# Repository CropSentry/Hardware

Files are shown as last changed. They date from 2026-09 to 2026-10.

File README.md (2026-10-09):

# 🌱 CropSentry

**A fully-autonomous plant disease/condition detector that runs on solar power and features LoRa capability.**

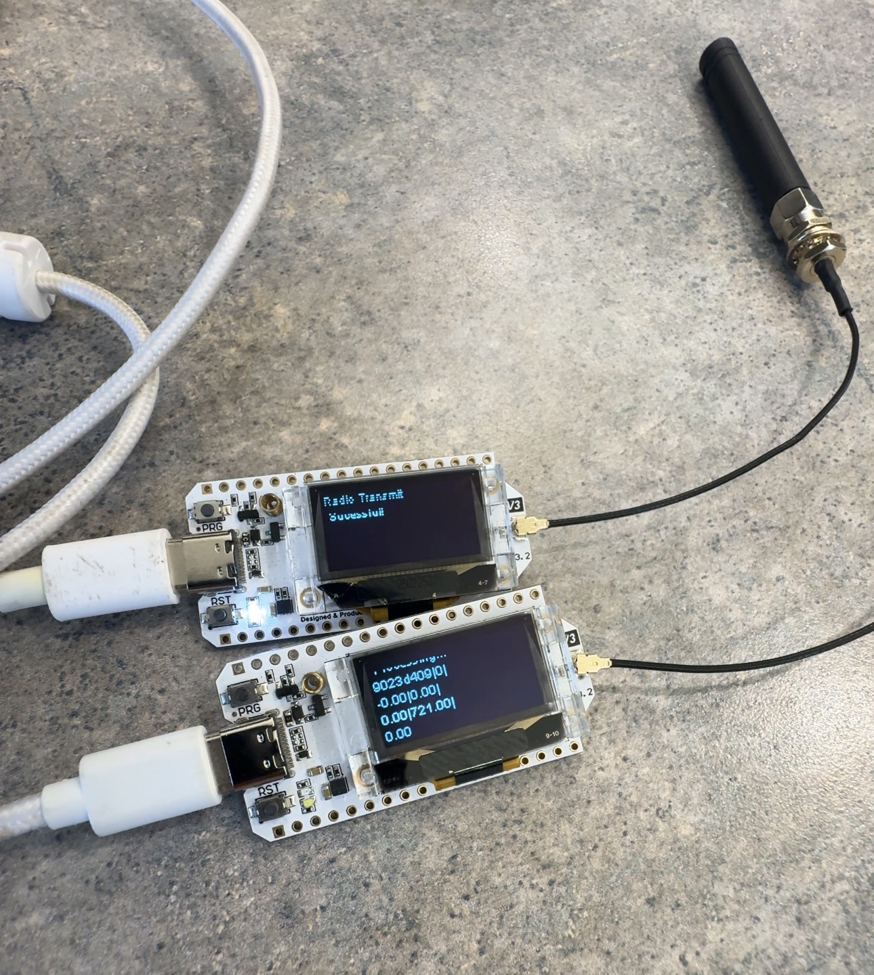
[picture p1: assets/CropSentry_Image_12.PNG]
Introduction Image 1


--------------

### 🔧 *What It Is*

**CropSentry** is an IoT device that automatically and autonomously tracks plant conditions, including VOC, temperature, soil moisture, gas, and humidity. It sits alone in a field and can monitor multiple crop sections at once. We see that through this process, an AI/ML model can use this data to determine the plant’s in-the-moment state, as well as provide an educated and accurate summary of what can show as a potential risk. 

The data path of how info will get to a user will start from the on-board module. (Cai Griffith) From there, it sends information via a LoRa connection to another board that is connected to a Wi-Fi router. The board will then send data over Wi-Fi to a high-power server (https://gear.museumofaviation.org/tech-specs/) and will compute all readings with an AI/ML system. (Jay Patel) After it’s been computed, the server will send the translated data to the CropSentry app. (Aahan Patel) From there, the user can read charts, numbers, and an AI summary of the condition of their crop.

**To summarize:**

- It's a plant disease/condition detector.
- It's a module that sends collected crop data to a powerful server for compute.
- It's a system of sensors full of cross-checking for accuracy.

--------------

### 🚗 *Drive*

CropSentry solves a real problem. Farmers all over the world need to constantly check their plants and make sure everything is doing well on a daily basis. According to statistics, over **20-40% of crops** are lost per year due to disease and environmental factors. It also says that an estimated **63+ tons of crops** and **220 billion dollars** are lost because of this.

With CropSentry, checking your crops/plants becomes automated, and you can do it all from your phone.

We see farmers as the cornerstone of our tech-evolving world, and we believe that a design like this could be very beneficial in the agricultural system.

--------------

### ⚙️ *How It Works*

The board chosen for the hardware design is the ***Heltec LoRa V3*** due to its high-level radio capabilities and adjustable range/power accessibility.

- **SGP41:** Detects VOC/NOx air pollution over a period of time using its metal-oxide sensor abilities. Sends data through Sensirion’s built-in VOC-translating algorithm. Primary gas sensor for accurate readings. Chosen for its ability to collect accurate information under low power and time.
- **BME688:** Looks specifically for temperature and humidity, but also serves as a secondary VOC sensor. Since VOCs are hard to track accurately, the BME688 can serve as an additional cross-check. Chosen for its high versatility and efficiency.
- **SHT45:**  Serves as the ambient system for temperature and humidity sensing. I also see this as another cross-check system, but it still carries weight in how data is calculated for the user. Chosen due to its low power draw, reduced pins, and sensor cross-checking abilities.
- **Capacitive Soil Moisture Probe:**  Detects soil moisture and processes all data on an ADC pin using analog information. I chose to use capacitive so the design wouldn’t corrode or get damaged during deployment.

Each sensor except the Soil Moisture Probe is connected via **I2C Connection**. The Soil Moisture Probe is connected to **GPIO 2** to receive analog signals.

--------------

### 🔋 *Power System*

```
6V 3W panel ──> Schottky ──> CN3065 charger ──> protected 18650 ──> Heltec VBAT
                                                       │
                                            load runs off the same node
```
--------------

### 💡 *Design Decisions and Potential Concerns*

- **Range:** This can be a concern, as we are not completely sure how far the LoRa system/data will transmit. This would mostly be because we are still working on designing the model (10/8/2026) and are not able to go into the testing phase yet.
- **Inaccurate Readings:** Specifically in the VOC/NOx sensors, where there is vulnerability due to them needing to be tested over time. We are virtually trusting the sensors’ datasheets to determine our readings.
- **Water Leaking**: Rainwater (especially heavy rainwater) has a possibility of breaking through the 3D-printed layer protecting the circuits. We are actively looking for a solution to this concern and are considering using remedies such as rubber seals, CNC-milled products, and absorbent material.
- **Calibration:** We are also relying on the datasheet for accurate calibration of all sensors. Similar to the BME688, we are taking multiple readings and using the median. We also have an embedded safeguard to not send data that is unrealistic and not plausible, such as, for example, a temperature reading showing as -200 Celsius.
- **Frequency:** I decided, on much advice and legal regulations, to go with the 902-928 MHz band, which is also known as the ISM band (Industrial, Scientific, and Medical band).
- **Coding Libraries:** For the hardware coding, I used the *heltec_unofficial.h*, *WiFiManager.h*, *HTTPClient.h*, *Wire.h*, *Adafruit_BME680.h*, and *Adafruit_SHT4x.h* libraries.

--------------

### 📐 *Schematic Images/PDF*

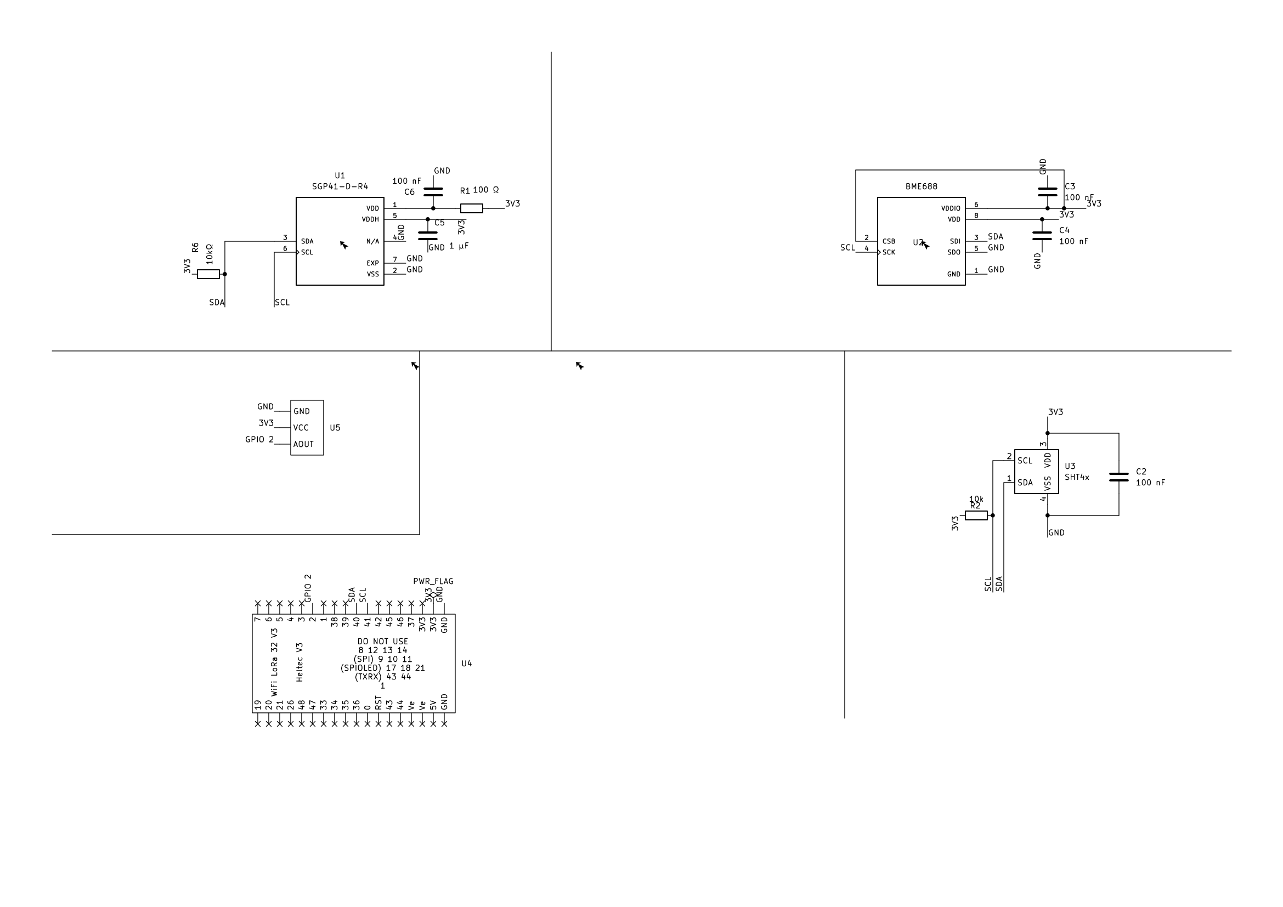
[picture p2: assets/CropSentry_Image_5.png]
Schematic PNG




--------------

### 🛠️ *CAD Images/3D Models*

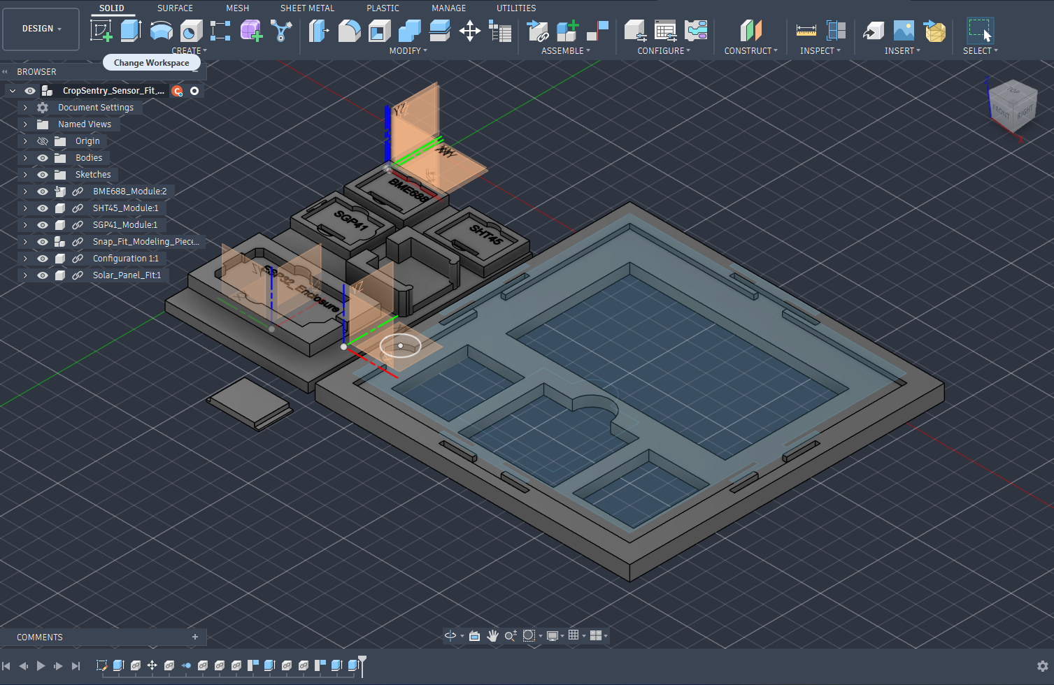
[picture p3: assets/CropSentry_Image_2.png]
CAD Image 1


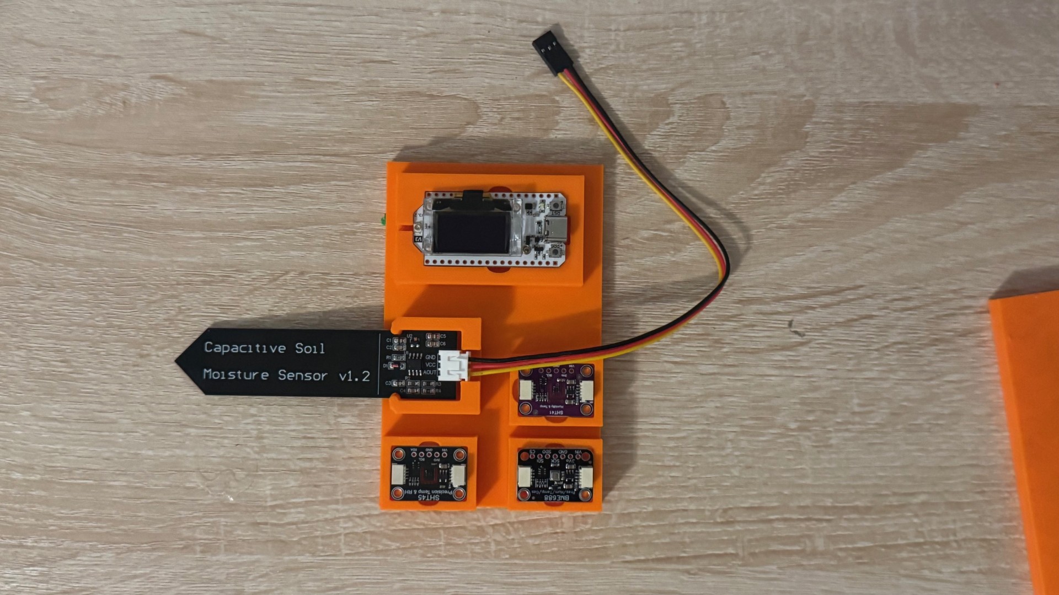
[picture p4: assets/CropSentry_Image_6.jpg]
3D Model Image 1


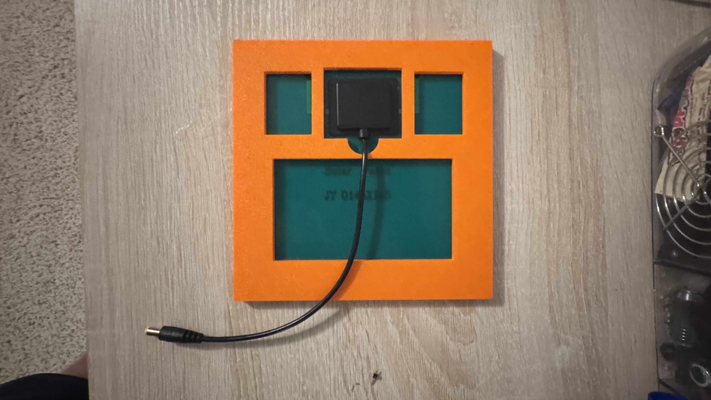
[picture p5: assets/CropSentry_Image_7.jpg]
3D Model Image 2


--------------

### 📋 *Bill of Materials*

| Part | Function | Qty | Price | Status |
| Part | Role | Qty | Cost | Status |
|---|---|---:|---:|---|
| **SGP41** | Primary VOC/NOx index sensor | 1 | $12.79 | *To buy* |
| **BME688** | Secondary gas + temp/humidity/pressure | 1 | $20.89 | ✅ Purchased |
| **SHT45** | Ambient temp/humidity reference | 1 | $14.99 | ✅ Purchased |
| **Capacitive soil probe** (EK1940, 2pk) | Soil water content, corrosion resistant | 1 | $9.99 | ✅ Purchased |
| **Heltec ESP32 LoRa V3** (w/ 1100 mAh cell + antenna) | MCU + SX1262 LoRa radio | 2 | $26.49 | ✅ 1 Purchased · 1 Donated |
| **ZPSHYD 6V 3W solar panel** | Monocrystalline, 145 × 145 mm | 1 | $14.59 | *To buy* |
| **XINLANTECH 18650 2600 mAh** | Protected Li-ion, built-in BMS | 1 | $11.72 | *To buy* |
| **CN3065 solar charge module** (3pk) | 500 mA solar Li-ion charger | 1 | $6.99 | *To buy* |
| **XT60 switch** | Battery disconnect | 1 | $8.99 | *To buy* |
| **Triple screw terminal** | Soil probe interface | 1 | — | 🔧 On hand |
| **Schottky diode** (40V 5A) | Reverse current blocking | 1 | — | 🔧 On hand |
| **Bulk electrolytic** (1000 µF 10V) | LoRa TX transient smoothing | 1 | — | 🔧 On hand |

### Budget

| Line | Submitted | Actual | Δ |
|---|---:|---:|---:|
| Subtotal | $135.43 | 127.44|-7.99 |
| Tax (7%) | $9.48 | 8.92|-0.56 |
| **Total** | **144.91**|**136.36** | **-$8.55** |
| Spent so far | $77.43 | $77.43 | — |
| **Remaining** | **67.48**|**58.93** | **-$8.55** |

*All on-hand pieces are CURRENTLY funded by me and other contributors; any money received from Stardance will go towards buying more parts needed and covering part expenses. Due to shipping and time concerns, I had to purchase parts myself to be able to continue building CropSentry on a strong timeline.*

--------------

### ⚡ *Visual Data Flow*

Architecture diagram of cropsentry/hardware (https://gitdiagram.com/cropsentry/hardware?utm_source=readme&utm_medium=picture)



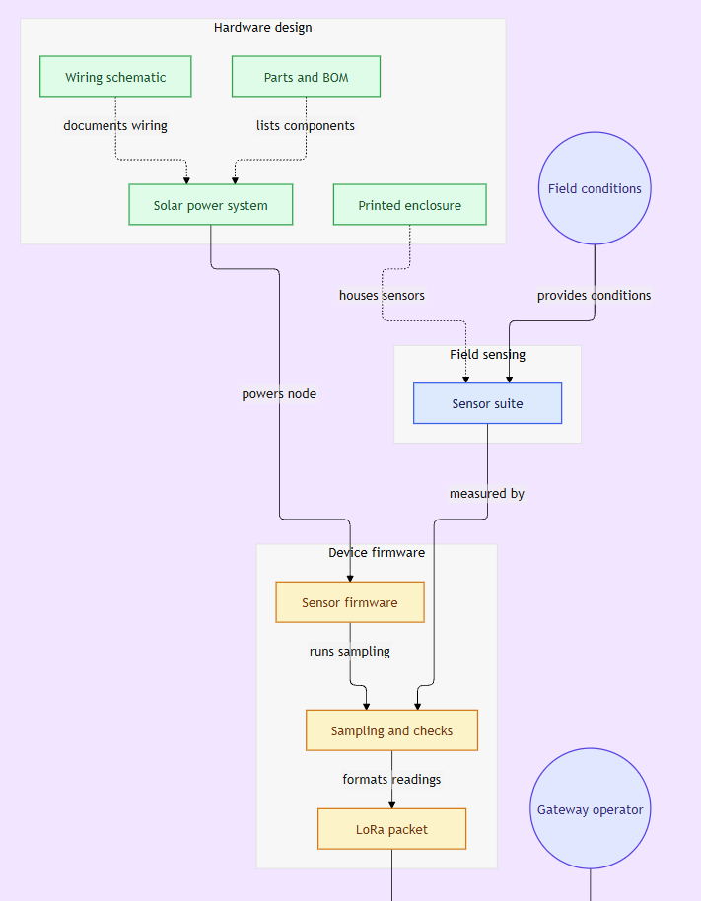
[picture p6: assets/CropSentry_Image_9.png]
Diagram Image 1

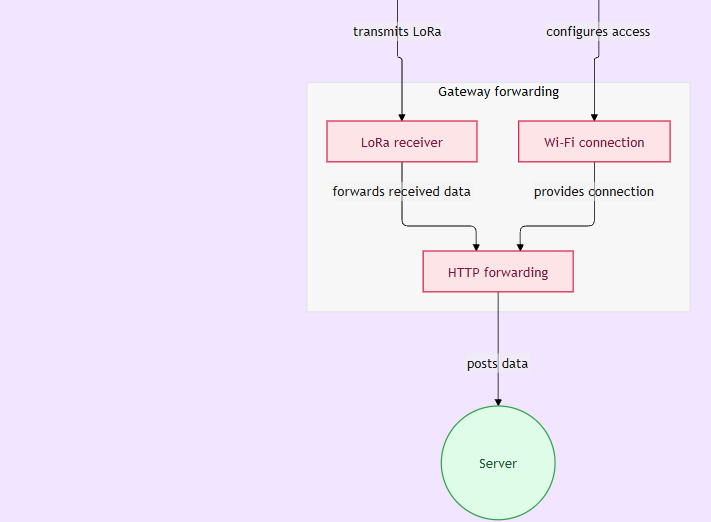
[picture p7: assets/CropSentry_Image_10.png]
Diagram Image 2


--------------

### 🔨 Building it Yourself

Make sure you have these libraries installed in your IDE/codespace: *heltec_unofficial.h v.9.2*, *WiFiManager.h v2.0.17*, *HTTPClient.h v.6.1*, *Wire.h v3.3.12*, *Adafruit_BME680.h v2.0.6*, and *Adafruit_SHT4x.h v1.0.5*.

In the receiver module code, change line 121 to your server link.

After that, make sure to plug in and run the receiver board code first; make sure to use the interactive Wi-Fi portal to connect the board to your router (You can do this by connecting to the board Wi-Fi from your device).

When the receiver board is set up, you can plug in and start the mainboard, which will automatically collect readings and send data to the receiver board.

Once that's done and all your devices are connected, everything is automated on a set timeframe, given there are no concurrent issues.

--------------

### 📄 *Extra Information*

- All CropSentry Hardware is coded in ***C++***

- The receiver code has an example link for where the server link is supposed to go due to security concerns. You must change this to send information to a server.

- CropSentry is a three-person project built for the **Congressional App Challenge** and approved as a research project through the **Middle Georgia State University CyberKnights Program**.

- ***All work regarding software, hardware, and planning is all designed by our team (only high schoolers).*** 

- We do have mentors who only give advice, but **all work is done by us**.

***Please also keep in mind that some of the files on here, such as code or 3D models, may have inaccuracies, as this is a work in progress. We are still in beta testing and are actively fixing these errors.***

--------------

### 🎬 *Presentations given at Middle Georgia State University CyberKnights Program*

**Public link to presentation created for a research meeting:** ***[Presentation View Link](https://github.com/CropSentry/Hardware/blob/main/research-presentations/Introduction/CropSentry_MGA_Presentation.pdf)***

**Public link to presentation created for an update at a research meeting (9-28-2026):** ***[Presentation View Link](https://github.com/CropSentry/Hardware/blob/main/research-presentations/Update_9-29-2026/CropSentry_Update_MGA_Presentation_9-28-2026.pdf)***

--------------

### 🏆 *Credits*

- **Hardware, power system, enclosure, and node firmware:** ***[Cai Griffith](https://www.caigriffith.dev)*** — *https://github.com/CropSentry/Hardware*
- **Application and server backend/frontend:** ***[Aahan Patel](https://github.com/HarbingerYt)*** — *https://github.com/CropSentry/MobileApp*
- **ML Design and backend:** ***[Jay Patel](https://github.com/Jay2710-09)*** — *Building ML Model; kept private in CropSentry*

--------------

### 🖼️ *Additional Images*

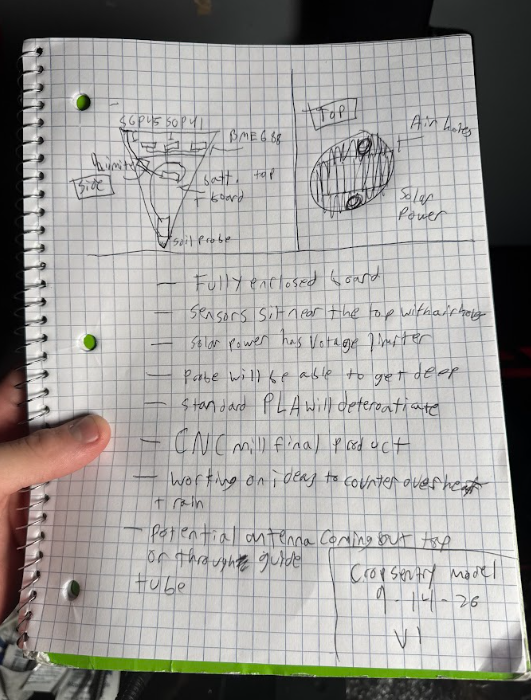
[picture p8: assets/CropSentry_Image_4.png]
Drawing Image 1

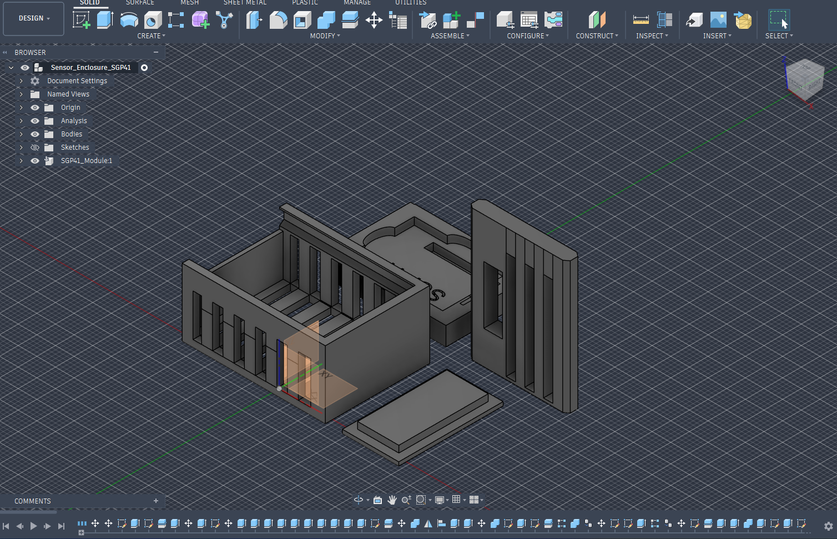
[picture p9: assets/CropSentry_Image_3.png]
CAD Image 2

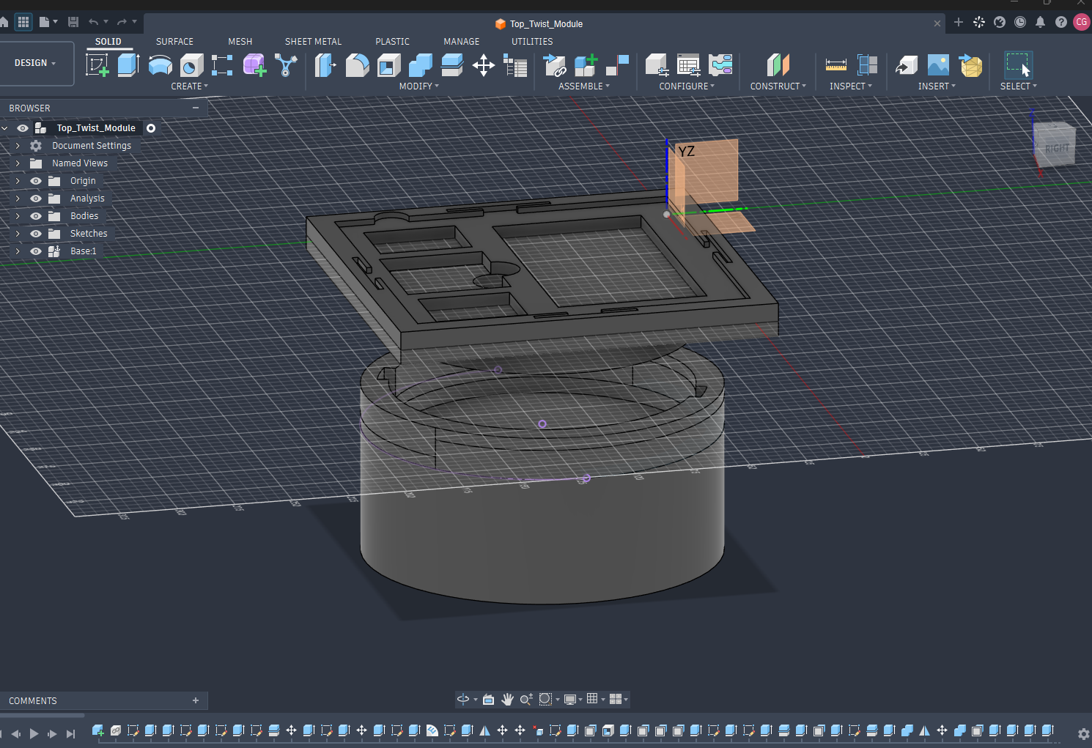
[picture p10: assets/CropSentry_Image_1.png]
CAD Image 3


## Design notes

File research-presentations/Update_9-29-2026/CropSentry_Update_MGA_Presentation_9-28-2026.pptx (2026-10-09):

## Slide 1

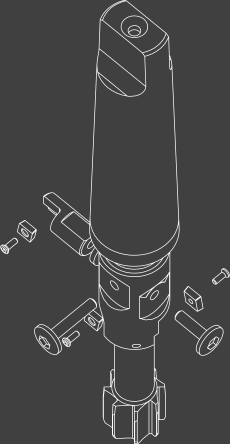
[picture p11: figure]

CropSentry
Update
Presentation

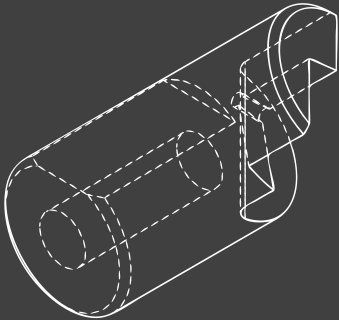
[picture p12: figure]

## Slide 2

Where we are

Currently, we are moving into the design phase of our project, pushing into physical manufacturing, finalizing code, and integrating the software/hardware.

What we’ve done

So far, we’ve made progress on all sides of CropSentry. The most notable progress is seen in App Development and Hardware with heavy advancement into further stages of building the project.

Where we plan to be

These upcoming weeks for CropSentry will be heavy on design. We plan to build physical models/prototypes, add more integration to the app and its user interface, and build a working machine learning system.

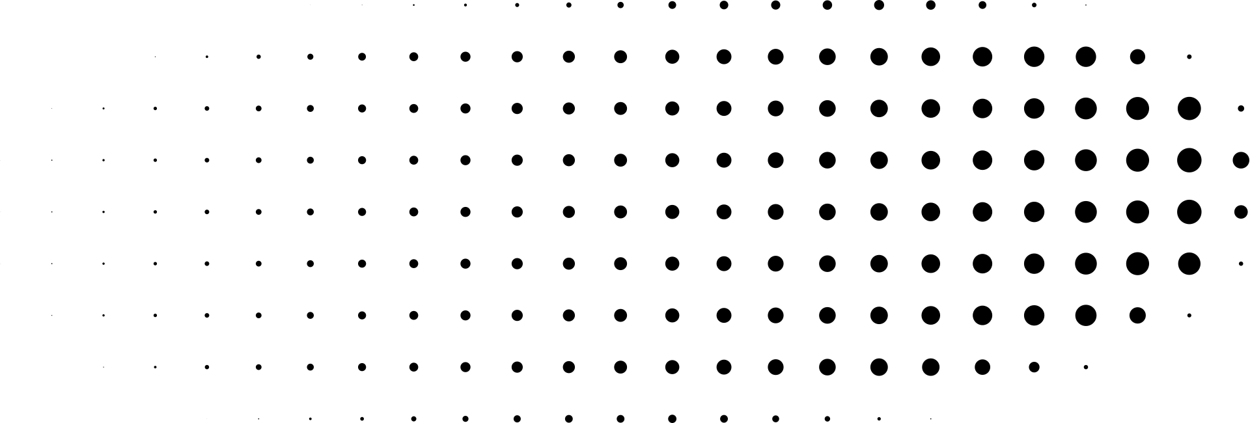
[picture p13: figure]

General Update

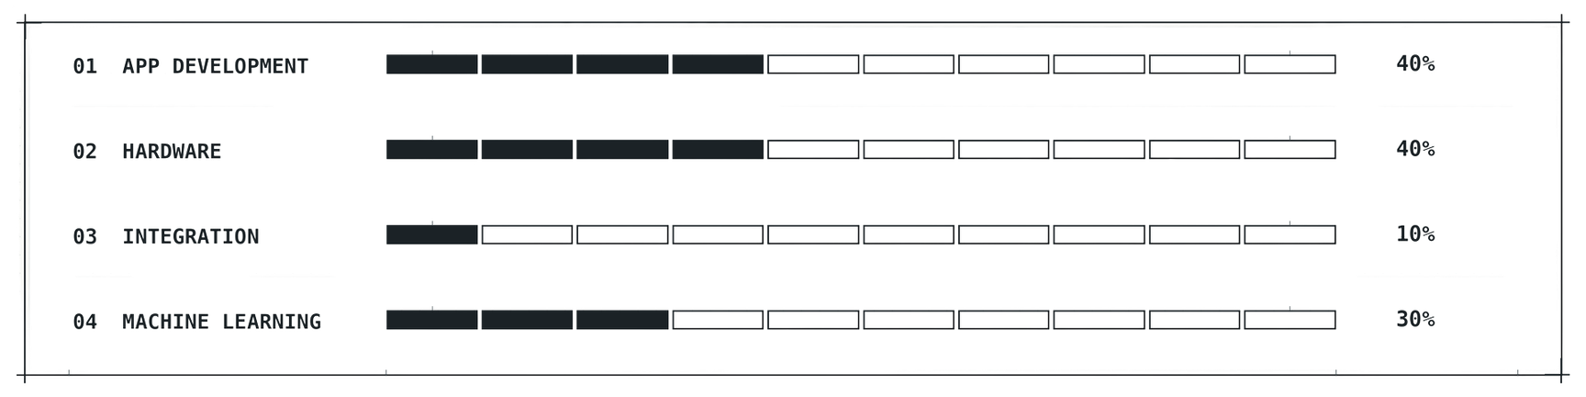
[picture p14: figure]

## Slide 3

Hardware

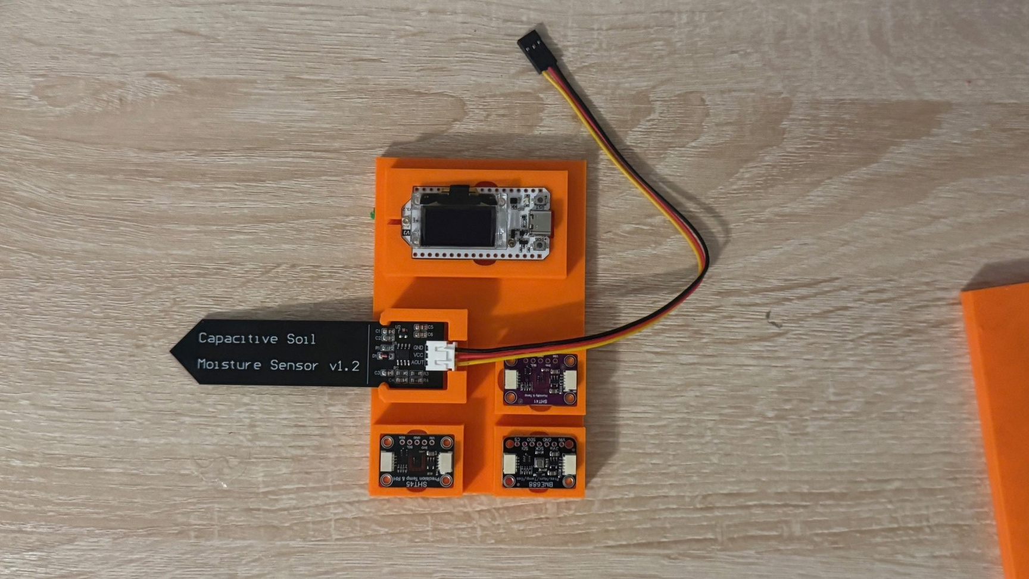
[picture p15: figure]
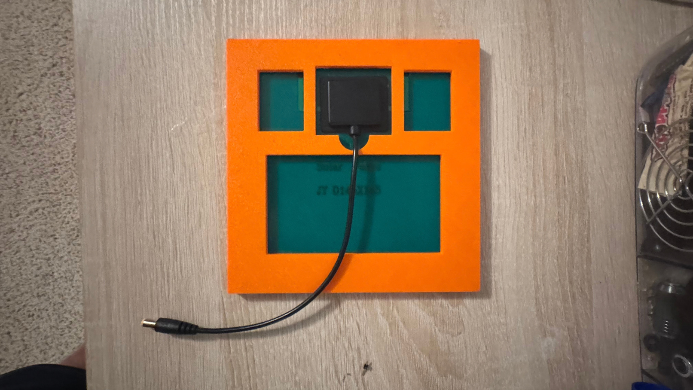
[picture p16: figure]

Prototyping

In hardware, we have physical 3D models to press-fit the sensors in, as well as a sizing estimate of how big the module will be

More Improvement

I have also built a diagram showing how the build will most likely be shaped. This will give us a valid estimate of how much area the device would take up.
In addition to that, we are close to completing the hardware code for the onboard module. The next steps for finishing it would be to write code to send the data collected over LoRa.

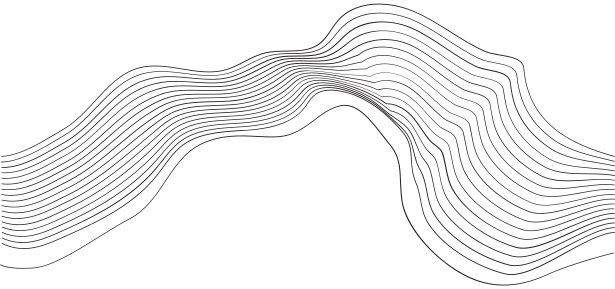
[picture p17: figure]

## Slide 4

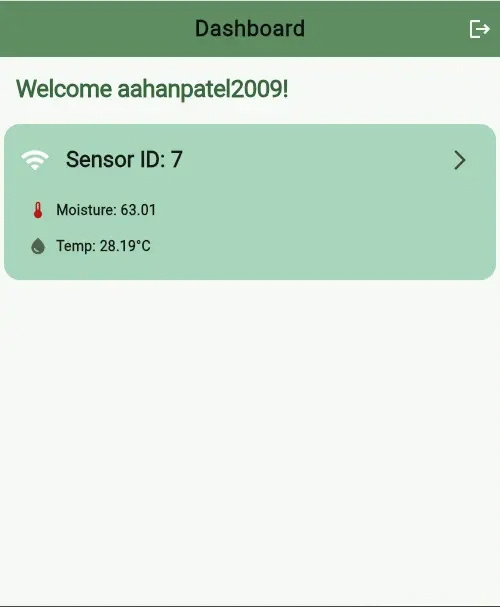
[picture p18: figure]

CropSentry App

Over the last few weeks, Aahan coded the frontend app for CropSentry. In it, you can make an account, add multiple devices, view an informational graph, and, looking further, review an AI summary of your information.

Software

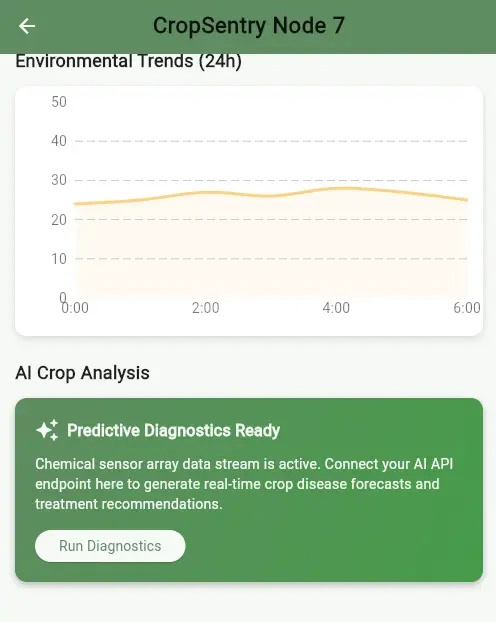
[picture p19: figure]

Looking Foward

Aahan is working on continuing the backend and is currently programming data integration throughout the app. The current goal is to get data flowing through the frontend as soon as realistically possible.
We have also recently received permission to use the Museum of Aviation’s new GEAR Lab server for app and device computation, which we will be actively working on to integrate all fields of software onto their machine.

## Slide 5

Machine Learning

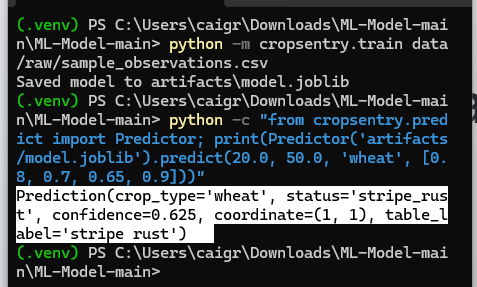
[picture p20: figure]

What is it?

The CropSentry Machine Learning System predicts whether a crop observation is healthy or has stripe_rust from temperature, moisture, crop type, and a fixed-order list of VOC measurements. Yellow-rust observations are grouped under the stripe_rust status.

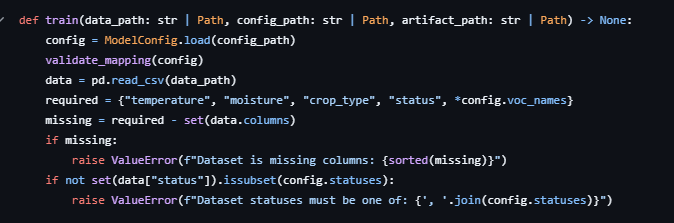
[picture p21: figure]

Progress Made

So far, Jay has coded the model to make a prediction based on a given data value. It prints 5 output variables so the user can see what a potential concern would be within their crop.

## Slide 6

See our work

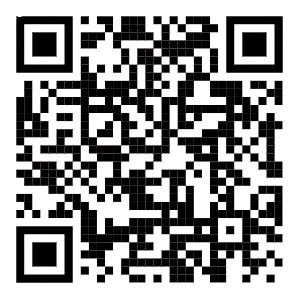
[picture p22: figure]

GitHub Link

If anyone is interested in keeping up with the CropSentry project, you can find our GitHub Organization link here:

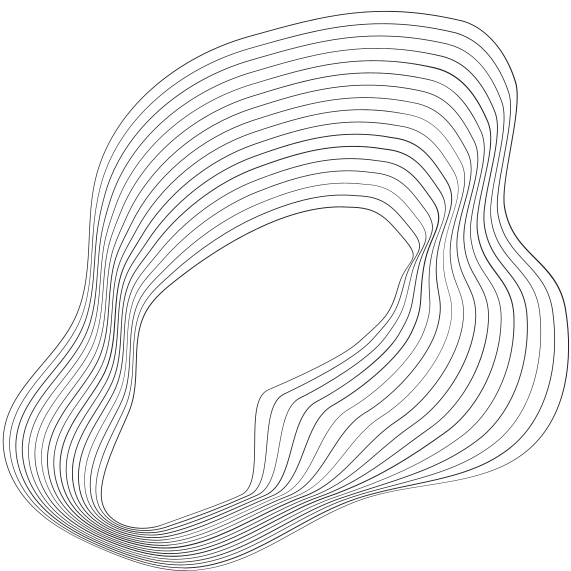
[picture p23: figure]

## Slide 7

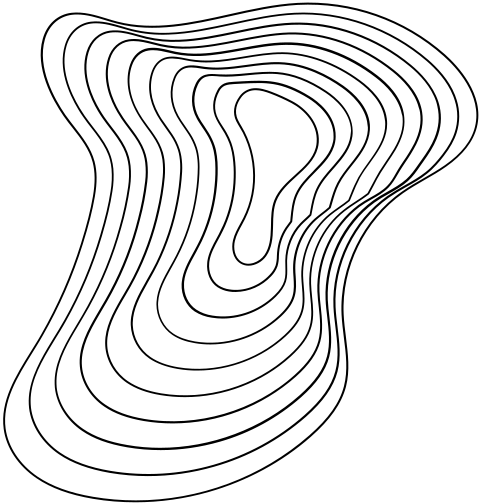
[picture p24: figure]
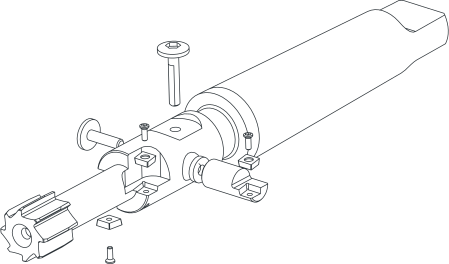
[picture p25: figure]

Q/A

Thank you for being a part of this presentation! Any questions are appreciated.

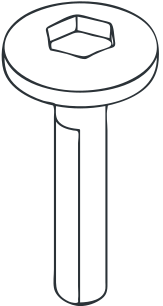
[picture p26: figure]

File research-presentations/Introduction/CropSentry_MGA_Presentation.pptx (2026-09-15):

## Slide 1


CropSentry
Research
Presentation


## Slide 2

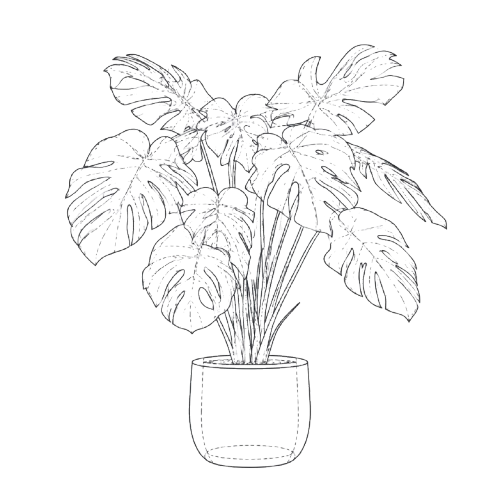
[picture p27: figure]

The Problem

Industry Concerns

Over $60B is spent annually on crop protection applied on a calendar schedule or after symptoms appear, not when stress begins.

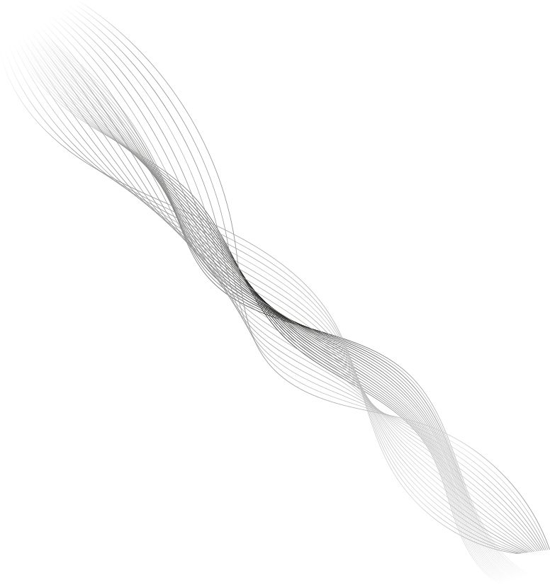
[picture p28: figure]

$220B

Lost from plant disease

20-40%

Globally lost plants due to diseases

63M+ tons

Lost crops in America from the past 4 years

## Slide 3

The Solution

Logic

VOC (Volatile Organic Compound) sensors read the air that a plant emits. A temperature and humidity sensor provides the ambient baseline, isolating the plant's signal from the environment's.
Using solar power to charge the module, CropSentry is able to run fully autonomously and without excessive maintenance.

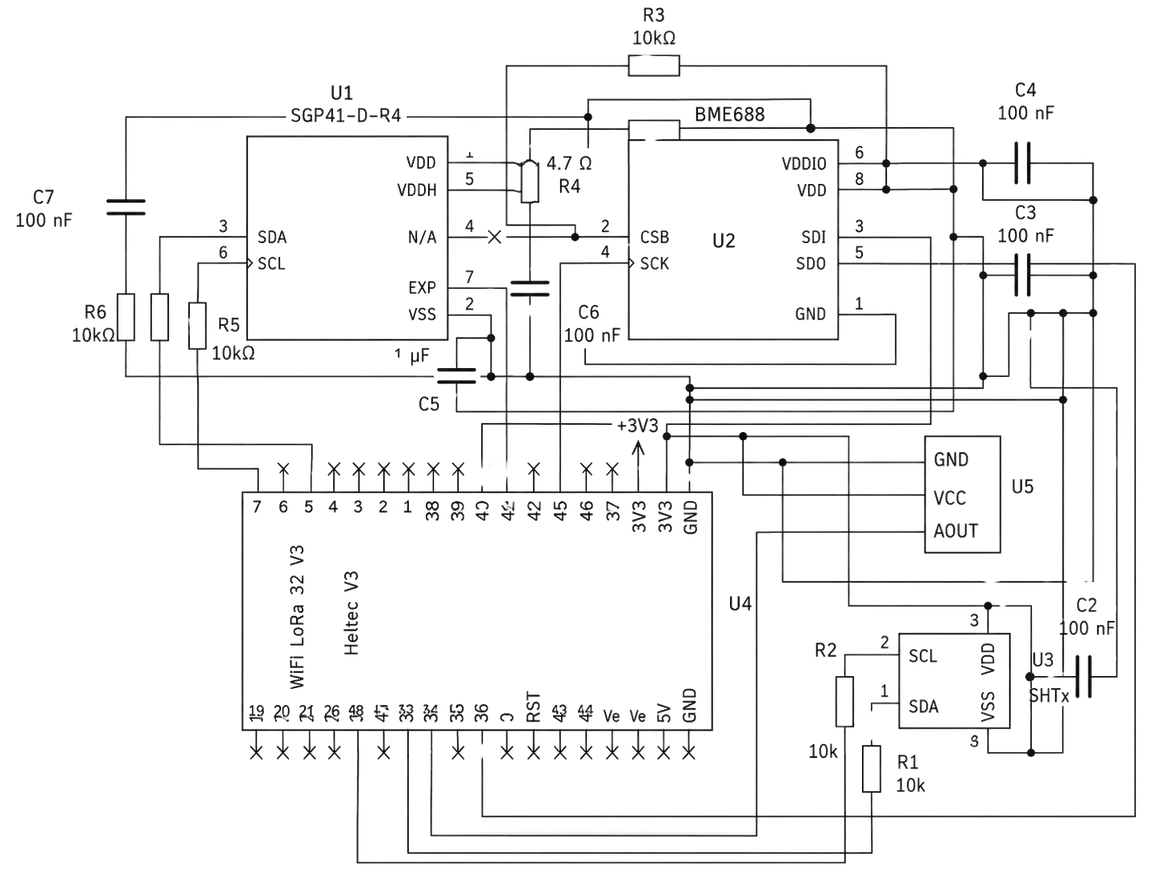
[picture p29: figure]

About the Project

CropSentry reads the compounds a plant emits, plus soil and ambient conditions, to catch stress before symptoms show. Nodes report to a gateway to your phone.


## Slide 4

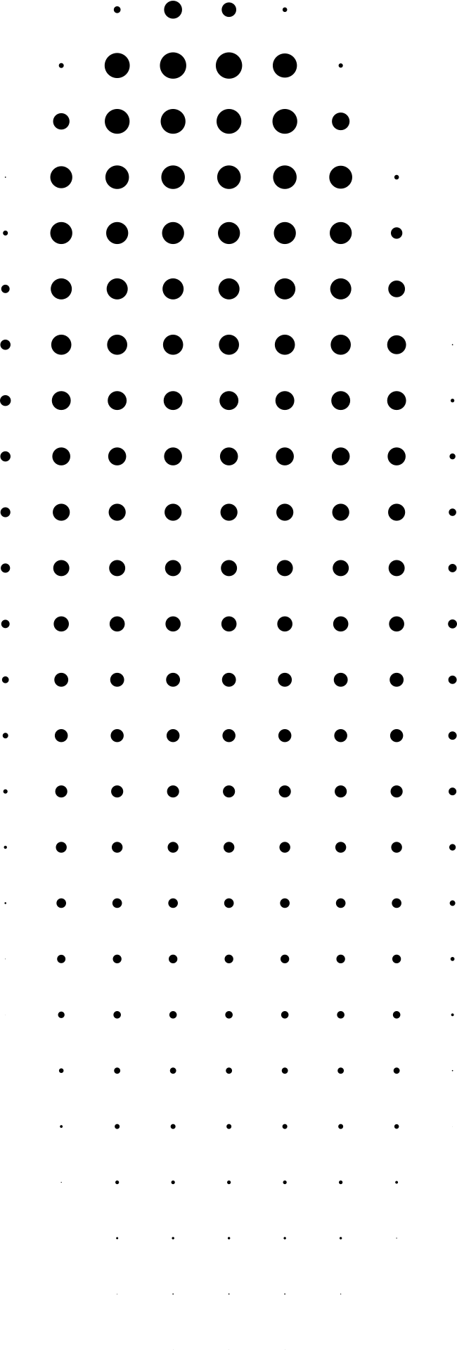
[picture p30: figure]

BME688

Checks for VOCs, temperature, humidity, and pressure

Hardware

SHT45

Secondary temperature and humidity sensor as an ambient system

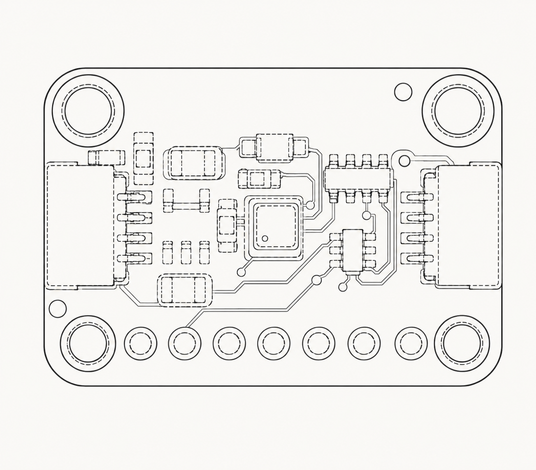
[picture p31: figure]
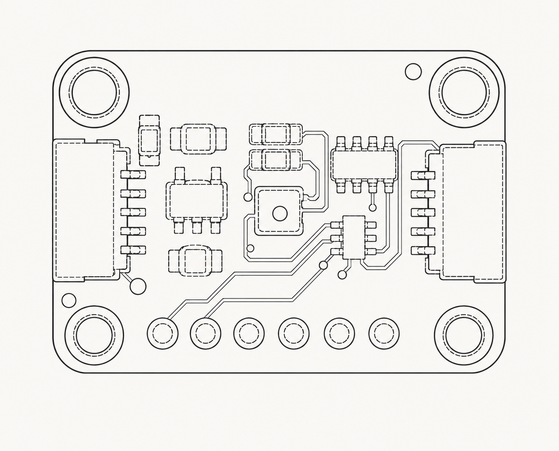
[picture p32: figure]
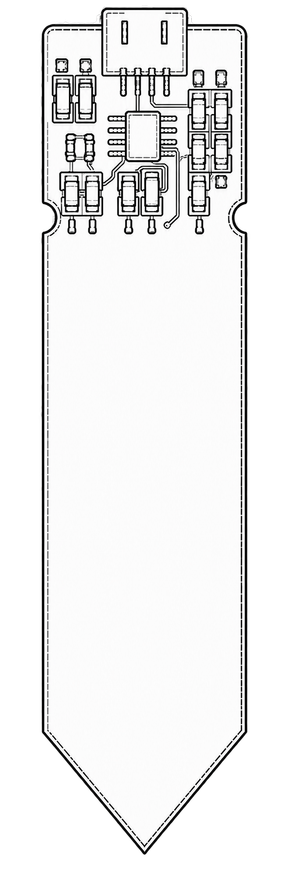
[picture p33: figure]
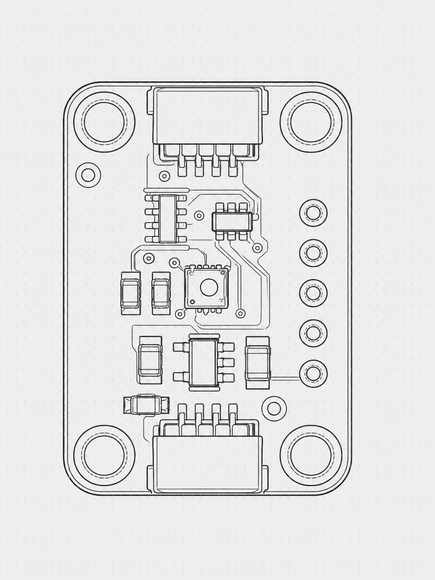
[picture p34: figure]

SGP41

Secondary VOC detection system to ensure accurate readings

Soil Moisture Probe

Detects when water in the soil is insufficient and sends an alert to the user for watering

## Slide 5


Data Logging

IO streams connecting data from server to app continuously

RT Dashboard

Live visual display of active sensor readings

History and Logs

Stored records and charts to track long-term performance

Authentication

Secure account creation, login, and profile management

ML Analysis

ML models that evaluate incoming data

Push Notifications

Instant threshold-based alerts sent to devices

Software

01


02

03


04

05


06


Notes: 1. Creating and storing user data for secure access to their farm data. This is done using Firebase Auth.
2. IO streams that connect to the server and app creating constant data streaming.
3. A machine learning model that is able to learn and detect when and what disease is in the field
4. Real time dashboard showing all the sentries
5. Push Notifications that the user can enable and receive immediately.
6. Graphs

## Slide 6

System Architecture

Vision

To use multiple methods of data transfer to ensure range while also providing accurate readings to the user


I

Starts by collecting 56 data samples and sending one collection of info via radio signal

II

Takes radio signal and processes data through WiFi to be received through a server

III

Server processes information and sends details to the user’s device through the app

IV

The app translates data and provides user-readable information about their plants

IV

The user can virtually interact with their plant and get a full diagnosis regarding diseases and health

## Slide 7


Continuous monitoring replaces manual scouting.

Detects stress before symptoms are visible.

One gateway serves many nodes across a field.


Runs unattended on solar for a full season.

Potential

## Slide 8


Q/A

Thank you for being a part of this presentation! Any questions are appreciated.


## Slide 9

Betts, A. K., Sisson, A. J., Ahumada, D. H., Allen, T. W., Anderson, N. R., Bergstrom, G. C., Bish, M., Bissonnette, K. M., Broderick, K. C., Byamukama, E., Chilvers, M. I., Collins, A. A., Duffeck, M. R., Esker, P. D., Faske, T. R., Friskop, A. J., Harbach, C., Heiniger, R. W., Isakeit, T., … Zeng, Y. (2026). Corn yield loss estimates due to diseases in the United States and Ontario, Canada, from 2020 to 2023. Plant Health Progress, 27(2), 257–268.
Food and Agriculture Organization of the United Nations. (2019, March 4). New standards to curb the global spread of plant pests and diseases.
Food and Agriculture Organization of the United Nations. (2026, July 21). The hidden health crisis: How plant diseases threaten global food security.

References

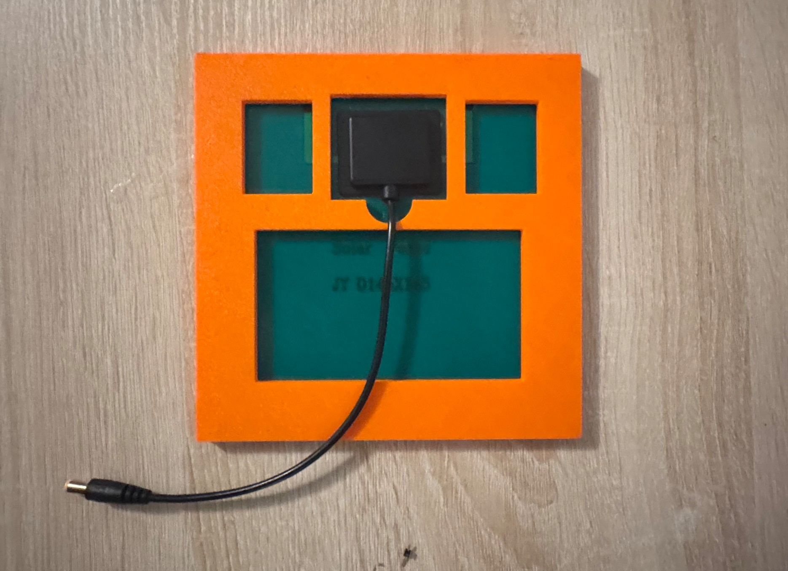
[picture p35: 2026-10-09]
assets/CropSentry_Image_8.jpg

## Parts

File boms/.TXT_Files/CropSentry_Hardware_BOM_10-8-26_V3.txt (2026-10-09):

CropSentry Hardware BOM:
____________________________________

Triple Screw Terminal (Already have) (1)

SHT45 (1) - 14.99$

BME688 (1) - 20.89$

SGP41 (1) - 12.79$

ESP32 LoRa V3 Module Board with 1100mAh Battery Set - with 863-928MHz Antenna and SX1262 LoRa V3 Devices for Meshtastic Arduino LoRawan IOT (2) - 26.49$ (1 purchased, 1 donated - 0.00$)

ZPSHYD 6V 3W Solar Panel, Mini Monocrystalline DC5521 for Battery Lamp (1) - 14.59$

XINLANTECH 3.7V 2600mAh 18650 Rechargeable Li-ion Battery with Jst XH2.54/2P (1) - 11.72$

3Pcs 500Ma Mini Solar Lipo Charger Board CN3065 Lithium Battery Charge Chip DIY Outdoor Charging Board Module (1) - 6.99$

Schottky Diode (Already have) (1)

Capacitive Soil Moisture Sensor Corrosion Resistant for Arduino Moisture Detection Garden Watering DIY (Pack of 2PCS) EK1940 (1) - 9.99$

Bulk Electrolytic 1000 microF 10V (Already have) (1)

XT60 Switch (1) - 8.99$
____________________________________

Tax in my area is 7%

Subtotal = 127.44$
Tax = 8.92$
Total = 136.36$ tax included
Spent so far = 77.43$
Remaining = 58.93$

Bought SHT45, SHT41, BME688, ESP32 LoRa V3 and Capacitive Soil Moisture Sensor
Received 2nd ESP32 LoRa V3 (donated)
Removed JST PH2.0 connector kit (returning)

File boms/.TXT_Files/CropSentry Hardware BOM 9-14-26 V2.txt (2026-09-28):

CropSentry Hardware BOM:
____________________________________

Triple Screw Terminal (Already have) (1)

SHT45 (1) - 14.99

BME688(1) - 20.89$

SGPz41 (1) - 12.79$

ESP32 LoRa V3 Module Board with 1100mAh Battery Set - with 863-928MHz Antenna and SX1262 LoRa V3 Devices for Meshtastic Arduino LoRawan IOT (1) - 26.49$

ZPSHYD 6V 3W Solar Panel, Mini Monocrystalline DC5521 for Battery Lamp (1) - 14.59$

XINLANTECH 3.7V 2600mAh 18650 Rechargeable Li-ion Battery with Jst XH2.54/2P (1) - 11.72$

3Pcs 500Ma Mini Solar Lipo Charger Board CN3065 Lithium Battery Charge Chip DIY Outdoor Charging Board Module (1) - 6.99$

30PCS JST ph2.0 Connector Female and Male jst ph2.0 Wire Cables 100mm jst ph 2.0 Connector kit (1) - 7.99$

Schottky Diode (Already have) (1)

Capacitive Soil Moisture Sensor Corrosion Resistant for Arduino Moisture Detection Garden Watering DIY (Pack of 2PCS) EK1940 (1) - 9.99$

Bulk Electrolytic 1000 microF 10V (Already have) (1)

XT60 Switch (1) - 8.99$
____________________________________

Tax in my area is 7%

Total = 144.91$ tax included
Spent so far = 77.43$

Bought SHT45, SHT41, BME688, ESP32 LoRa V3 and Capacitive Soil Moisture Sensor

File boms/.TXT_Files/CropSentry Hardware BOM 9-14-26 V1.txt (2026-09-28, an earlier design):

CropSentry Hardware BOM:

Triple Screw Terminal (1)
SGP41-D-R4 (1)
BME688(1)
SHT4x (1)
Heltec V3 WiFi LoRa 32 V3 (1)
Capacitor SMD 100nF 0805_2012Metric (4)
Capacitor SMD 1µF 0805_2012Metric (1)
Resistor 10kΩ 0805_2012Metric (2) 
Resistor 100Ω 0805_2012Metric (1)

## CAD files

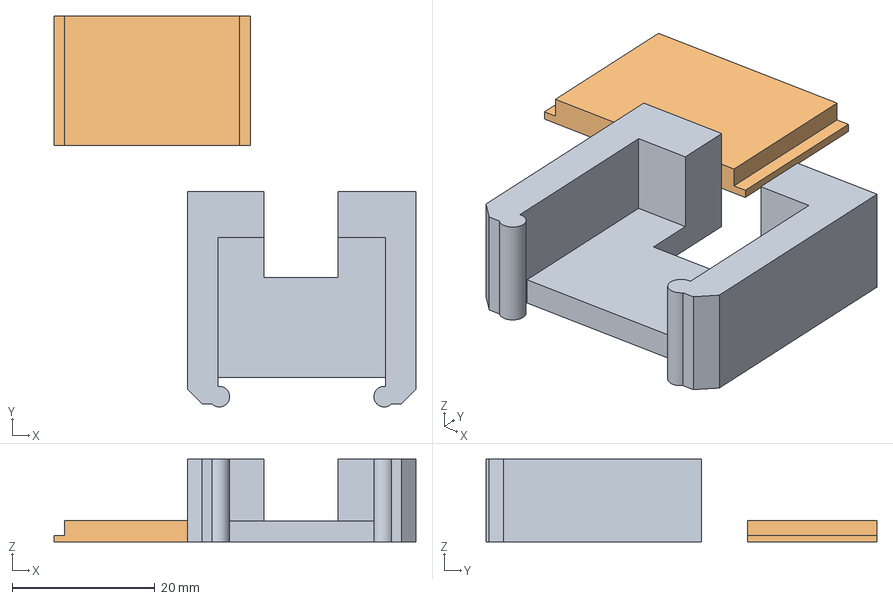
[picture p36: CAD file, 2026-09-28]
cad/Modeling/.STEP Files/Capacitive_Soil_Moisture_Probe_Module.step
50.7 x 54.7 x 11.6 mm

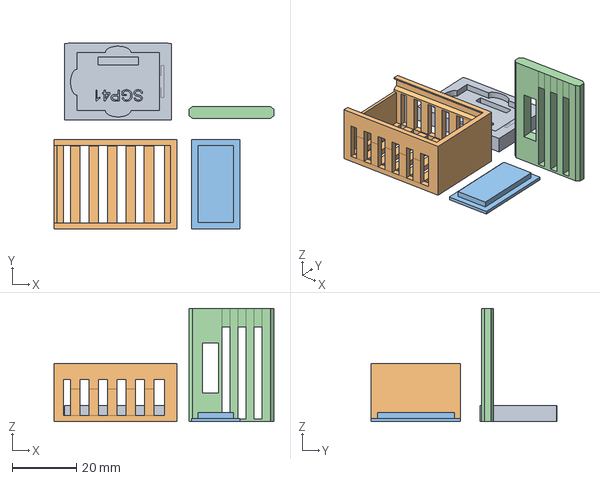
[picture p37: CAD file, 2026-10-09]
cad/Modeling/3D Sensor Enclosure Prototype/Sensor_Enclosure_SGP41.step
68.7 x 58.1 x 35.4 mm

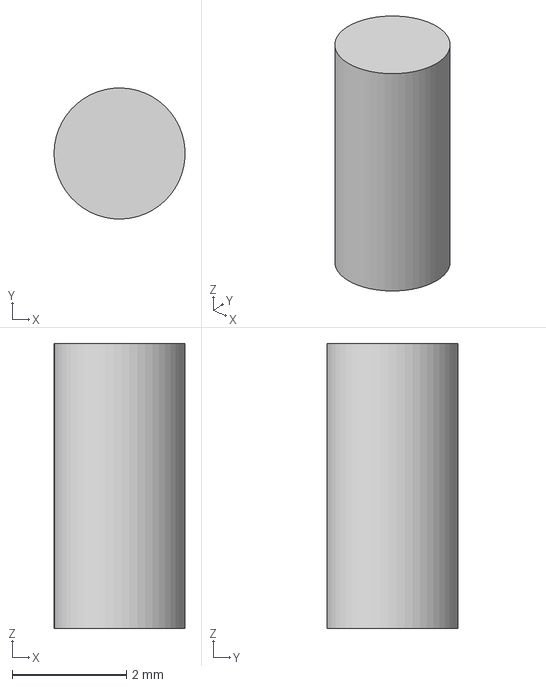
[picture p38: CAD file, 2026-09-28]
cad/Printing/Placeholder_Pin_MountFitTesting.step
2.30 x 2.30 x 5.00 mm

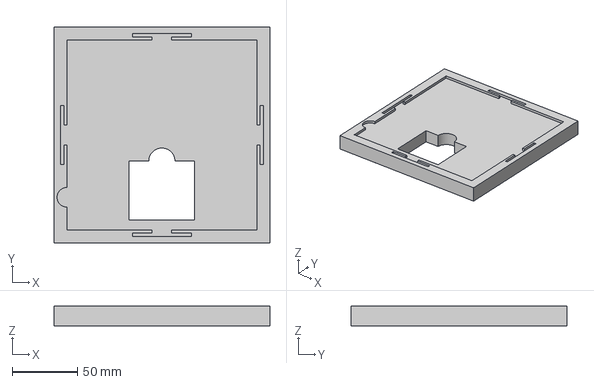
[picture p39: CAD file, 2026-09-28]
cad/Modeling/.STEP Files/Solar_Panel_Fit.step
165.0 x 165.0 x 15.0 mm

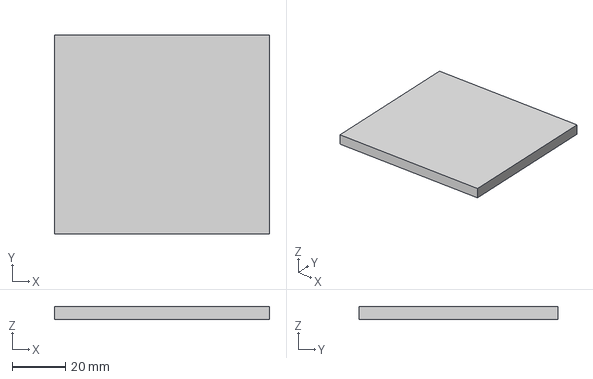
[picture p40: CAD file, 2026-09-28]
cad/Printing/Mount_Fit_Test.step
81.0 x 75.0 x 5.00 mm

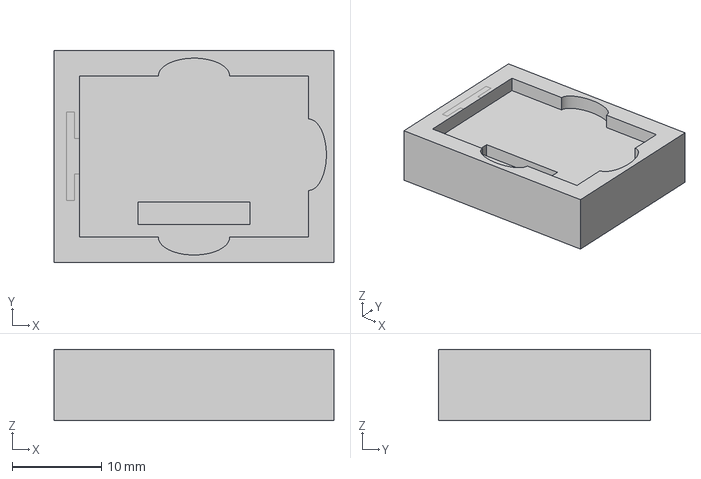
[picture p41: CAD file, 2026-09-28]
cad/Modeling/.STEP Files/SGP41_Module.step
31.4 x 23.8 x 8.00 mm

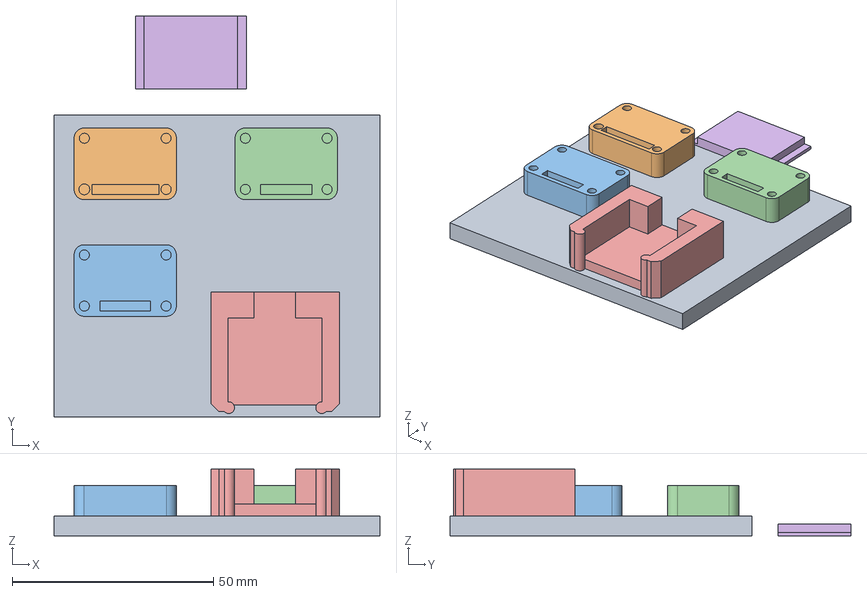
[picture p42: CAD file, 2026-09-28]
cad/Printing/Sensor_Mount_Test.step
81.0 x 99.6 x 16.6 mm

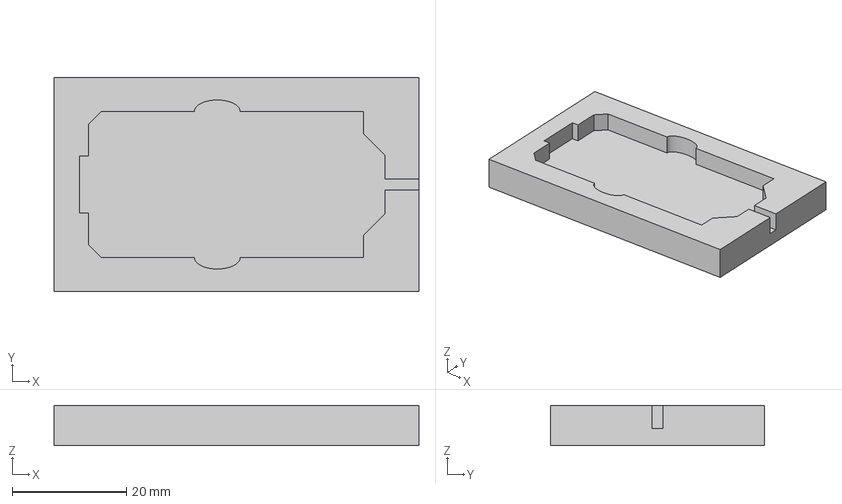
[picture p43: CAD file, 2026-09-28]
cad/Modeling/.STEP Files/Snap_Fit_Modeling_Piece.step
63.8 x 37.4 x 7.00 mm

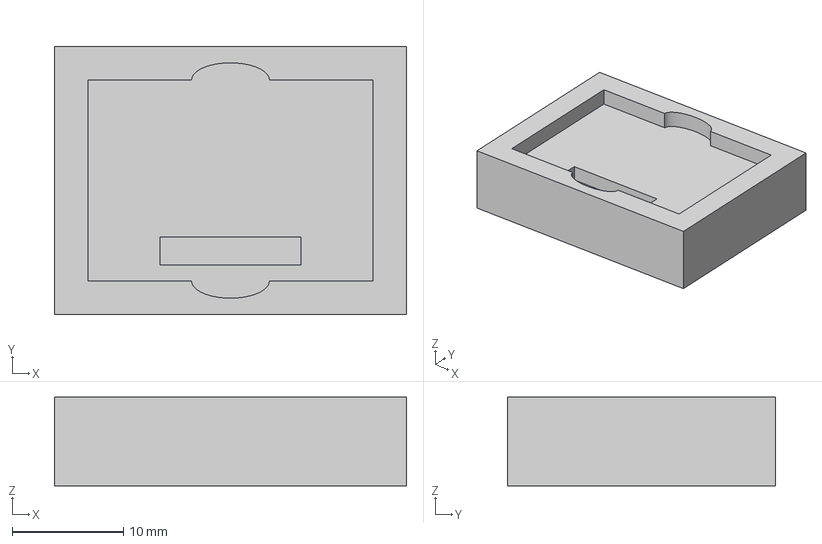
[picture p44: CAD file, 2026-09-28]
cad/Modeling/.STEP Files/SHT45_Module.step
31.7 x 24.1 x 8.00 mm

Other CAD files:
cad/Modeling/.STEP Files/ESP32_Heltec_LoRa_V3_Enclosure.step
cad/Modeling/.STEP Files/BME688_Module.step
cad/Modeling/.F3D Files/BME688_Module.f3d
cad/Modeling/.F3D Files/Capacitive_Soil_Moisture_Probe_Module.f3d
cad/Modeling/.F3D Files/ESP32_Heltec_LoRa_V3_Enclosure.f3d
cad/Modeling/.F3D Files/SGP41_Module.f3d
cad/Modeling/.F3D Files/SHT45_Module.f3d
cad/Modeling/.F3D Files/Snap_Fit_Modeling_Piece.f3d
cad/Modeling/.F3D Files/Solar_Panel_Fit.f3d
cad/Modeling/3D Sensor Enclosure Prototype/Sensor_Enclosure_SGP41.stl
cad/Printing/Mount_Fit_Test.f3d
cad/Printing/Placeholder_Pin_MountFitTesting.f3d
cad/Printing/Sensor_Mount_Test.f3d

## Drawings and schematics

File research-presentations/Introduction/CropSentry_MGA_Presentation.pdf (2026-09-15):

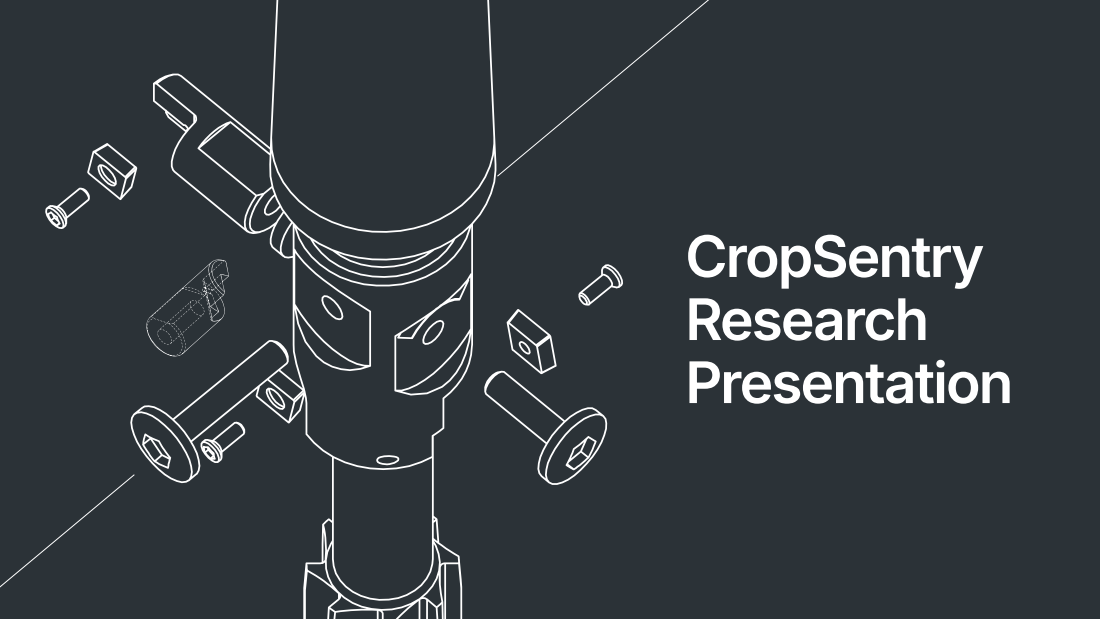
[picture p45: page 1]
CropSentry Research Presentation

T

h

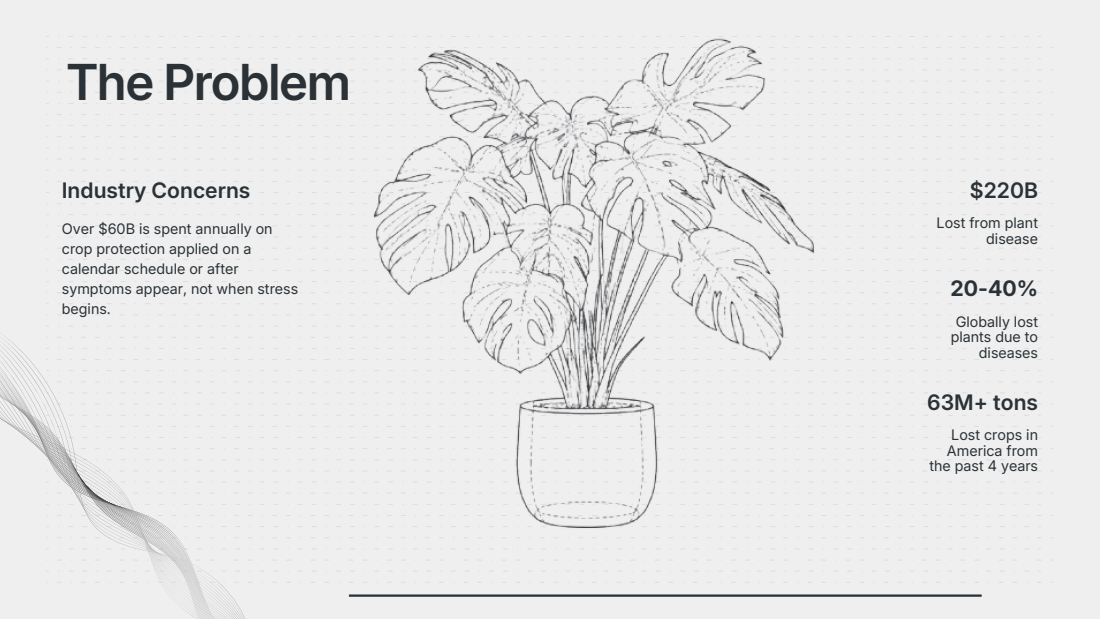
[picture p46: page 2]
ble; m Industry Concerns; ally; tio; plie; ale; ule; gin; pla; dis; Glo; ally lo; ric

T

h

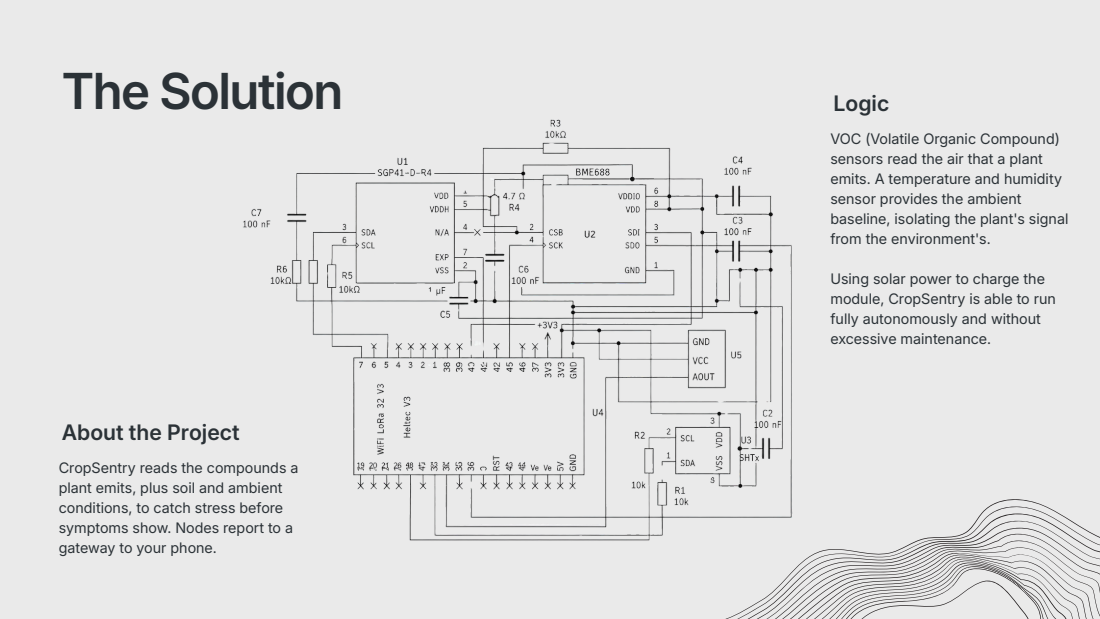
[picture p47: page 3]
olu; pla; mit; plu; oil a; bie; ditio; ola; tile; nic; air; midit; vid; elin; tin; sig

al from the environment's. Using solar power to charge the module, CropSentry is able to run fully autonomously and without excessive maintenance.

## SHT45

## BME688

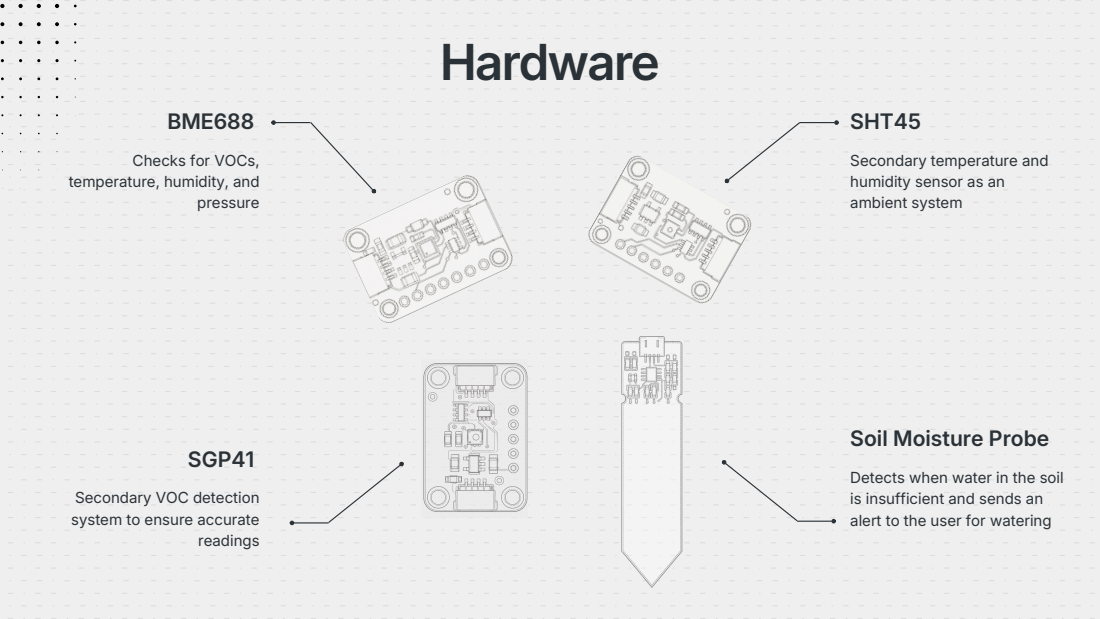
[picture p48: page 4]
pressure; SGP41; readings; Hardware

Checks for VOCs,

Secondary temperature and
humidity sensor as an
ambient system

temperature, humidity, and

Soil Moisture Probe

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

Secondary VOC detection
system to ensure accurate

# Software

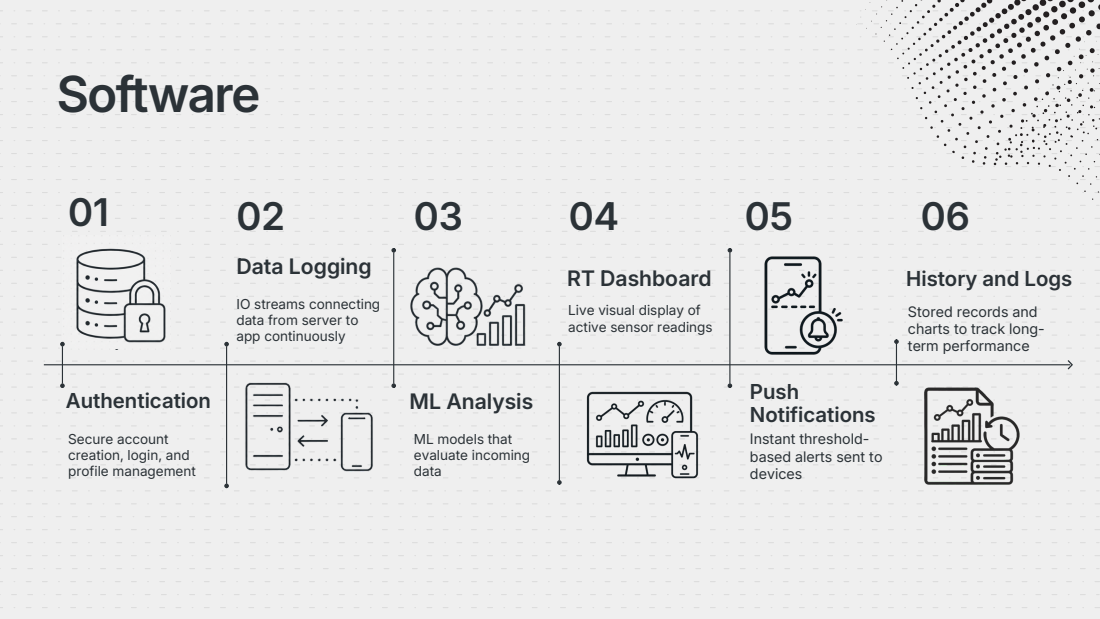
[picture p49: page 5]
Authentication; Data Logging; ML Analysis; RT Dashboard

History and Logs

IO streams connecting
data from server to
app continuously

Live visual display of
active sensor readings

Stored records and
charts to track long-
term performance

Push
Notifications
Instant threshold-
based alerts sent to
devices

Secure account
creation, login, and
profile management

ML models that
evaluate incoming
data

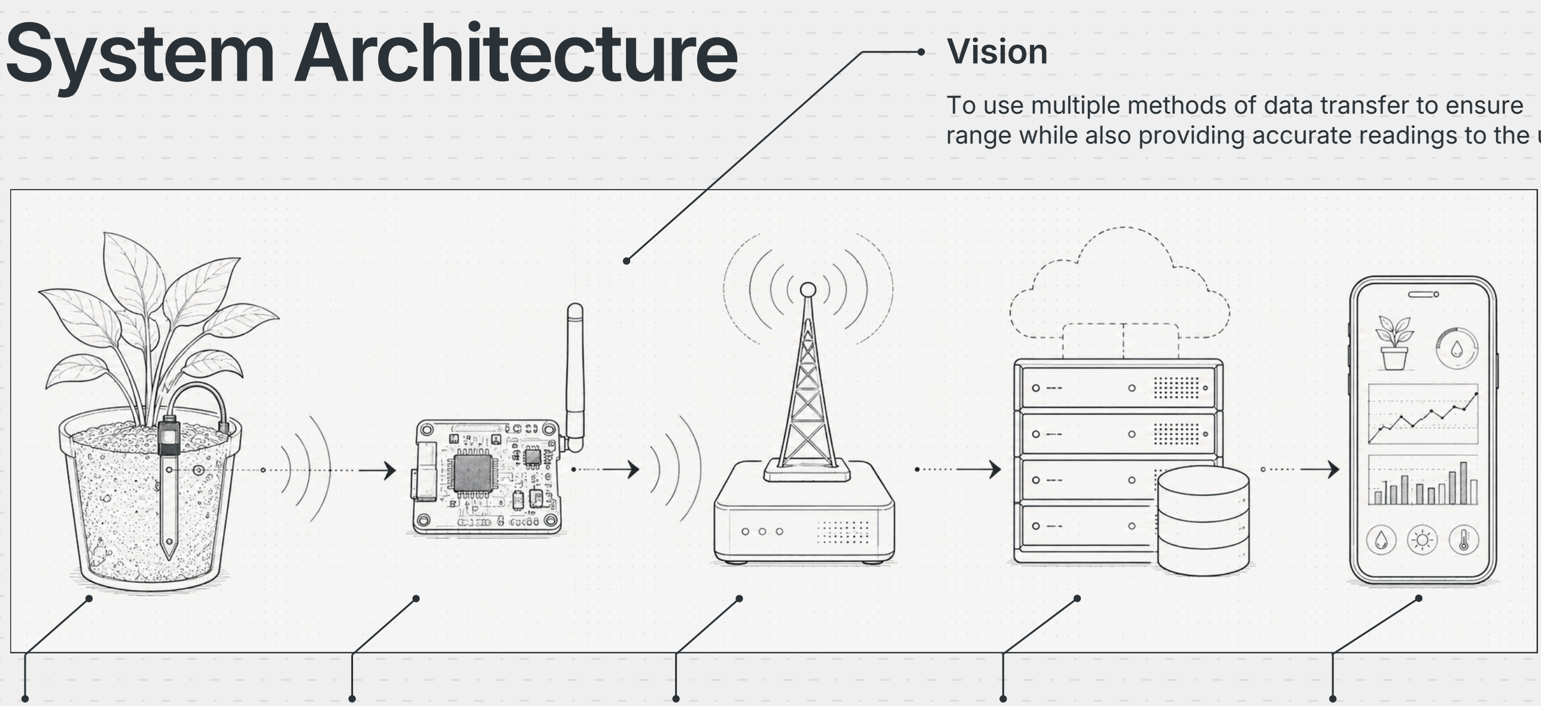
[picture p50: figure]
System Architecture; Vision

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

I

Starts by collecting 56
data samples and
sending one collection of
info via radio signal

Server processes
information and sends
details to the user’s
device through the app

## III

The app translates data
and provides user-readable information
about their plants
II | IV

Takes radio signal and
processes data through
WiFi to be received
through a server

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

IV

# Potential

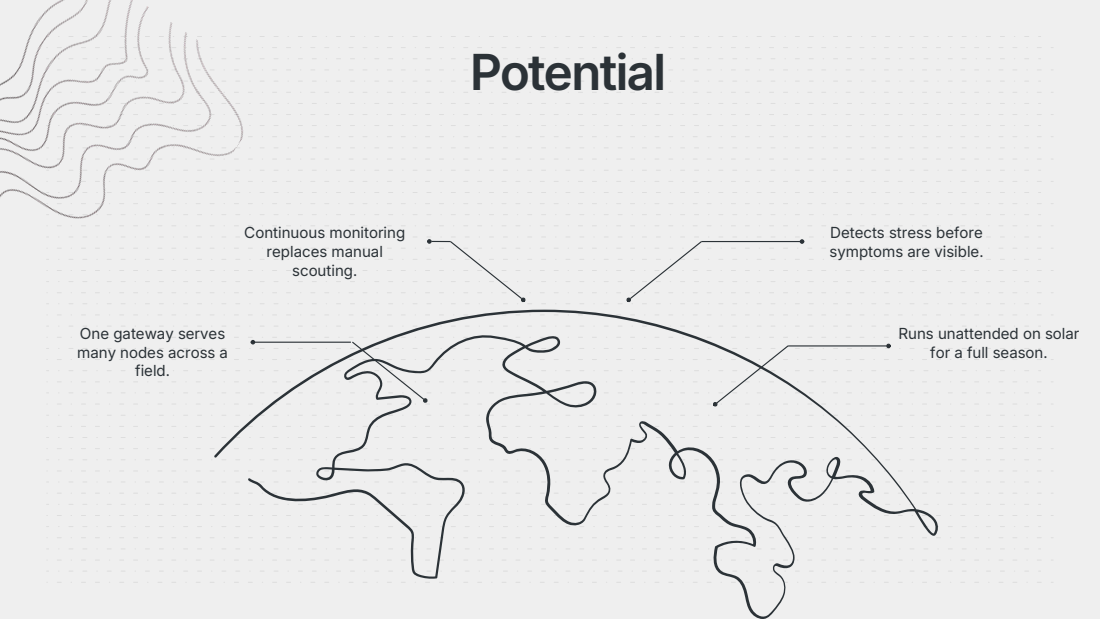
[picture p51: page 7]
Continuous monitoring replaces manual scouting.; field.

Detects stress before
symptoms are visible.

One gateway serves
many nodes across a

Runs unattended on solar
for a full season.

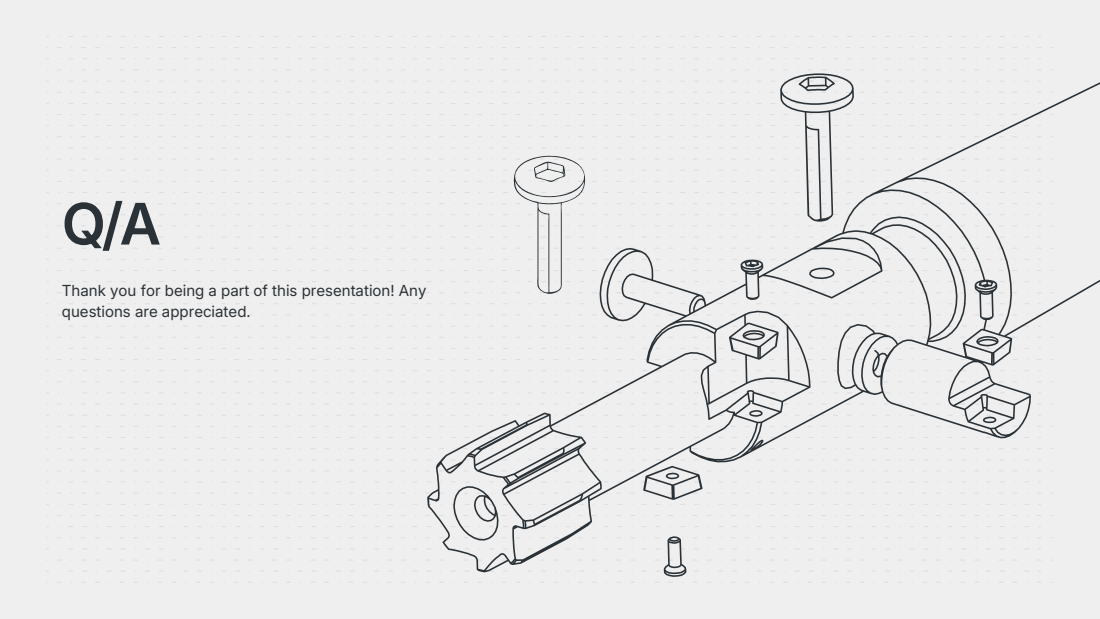
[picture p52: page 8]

Thank you for being a part of this presentation! Any
questions are appreciated.

# References

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

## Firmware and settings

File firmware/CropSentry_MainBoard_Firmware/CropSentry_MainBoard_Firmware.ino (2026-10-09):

#include <heltec_unofficial.h>
#include <Wire.h>
#include <Adafruit_BME680.h>
#include <Adafruit_SHT4x.h>
Adafruit_SHT4x sht4;

Adafruit_BME680 bme(&Wire);

#define PAUSE 0             // MS between packet transmission, already computed in void loop() - Will send when button pressed
#define FREQUENCY 905.2     // 905.2 MHZ, legal band for ISM - POWER MUST BE UNDER 30 dBm - ANTENNA UNDER 6 dBi
#define BANDWIDTH 500.0     // 500 kHz, MAKE SURE Serial BOARDS ARE SET TO THIS
#define SPREADING_FACTOR 9  // Controls how fast or slow board sends, longer should mean slower
#define TRANSMIT_POWER 0    // Boards are close together for testing - don't want to send too much transmit power

#define SM_A 2  // Soil Moisture Analog

int a = 0;  // Soil Moisture Sensor
int b = 0;  // Humid 2 Sensor
int c = 0;  // BME688 Reading Check
int d = 0;  // SHT45 Reading Check
int x = 0;  // Gas Sensor
int y = 0;  // Humid 1 Sensor
int z = 0;  // Temperature 1 Sensor
// Setting failsafe vars, if sensor repsonds with unrealistic numbers, terminate whole send
unsigned long lastRun = 0;
unsigned long waitTime = 0;
int iter = 0;       // Variable used to determine how many times to repeat loop after fail before device stops
int radioiter = 0;  // Used to determine whether the sensors or radio is failing
volatile bool rxFlag = false;

struct SensorPacket {
  uint64_t nodeid;  // Uses board SN for variety

  int sequence;

  float temp1;

  float humid1;
  float humid2;
  float soilm;
  float gas;

  // Needs verification, may count on server
  int samplec;

  // Needs sensor, looking at SGP41, but it might not come in the mail until October
  float temp2;
  float voc1;
  float voc2;
};

SensorPacket SensorData;



void setup() {
  heltec_setup();
  heltec_ve(true);  // Uses on-board VEXT pin for the displays 3V3 power source
  delay(100);
  pinMode(21, OUTPUT);
  digitalWrite(21, LOW);
  delay(50);
  digitalWrite(21, HIGH);
  delay(50);  // Sets pin 21 (display controller) LOW and HIGH for power configuration

  display.init();
  display.flipScreenVertically();
  SensorData.nodeid = (uint64_t)(ESP.getEfuseMac() >> 16);

  // limits the amount of numbers shown on the boards SN as a variable, keeps it usable for a finite and autonomous identification system

  display.clear();
  display.drawString(0, 0, "Starting Module");
  display.display();
  delay(5000);
  heltec_led(50);           // LED brightness, 50% is enough
  Serial.begin(115200);     // 115200 baud, 8 SensorData bits, N for no parity, 1 stop bit, on the SDA and SCL pins
  pinMode(SM_A, INPUT);     // Setting Soil Moisture Probe to an input
  SensorData.sequence = 0;  // Setting Sequence to 0

  RADIOLIB_OR_HALT(radio.begin());
  // Set the callback function for sending packets
  radio.startReceive();
  // Set radio parameters

  display.clear();
  display.drawString(0, 0, "Frequency: " + String(FREQUENCY, 2) + " MHz");
  display.display();
  delay(5000);
  Serial.printf("Frequency: %.2f MHz\n", FREQUENCY);
  RADIOLIB_OR_HALT(radio.setFrequency(FREQUENCY));

  display.clear();
  display.drawString(0, 0, "Bandwidth: " + String(BANDWIDTH, 1) + " kHz");
  display.display();
  delay(5000);
  Serial.printf("Bandwidth: %.1f kHz\n", BANDWIDTH);
  RADIOLIB_OR_HALT(radio.setBandwidth(BANDWIDTH));

  Serial.printf("Spreading Factor: %i\n", SPREADING_FACTOR);
  RADIOLIB_OR_HALT(radio.setSpreadingFactor(SPREADING_FACTOR));

  Serial.printf("TX power: %i dBm\n", TRANSMIT_POWER);
  RADIOLIB_OR_HALT(radio.setOutputPower(TRANSMIT_POWER));

  // Used LoRa_rx_tx.ino library for this block

  display.clear();
  display.drawString(0, 0, "Radio Initialized");
  display.display();
  delay(5000);
  Serial.println("Radio Initialized");
  // put your setup code here, to run once:
  // Wire1.begin(8, SDA, SCL);       // Sets general I2C address to 8
  // Wire1.onRequest(requestEvent);  // When told to request SensorData, run a function, such as void requestEvent()
  // Wire1.write((uint8_t*)&data, sizeof(data));
  display.clear();
  display.drawString(0, 0, "Device Initializing");
  display.display();
  delay(5000);
  Serial.println("Device Initializing:");

  if (!bme.begin()) {  // Checks for if BME is working
    display.clear();
    display.drawString(0, 0, "No BME688 Connected, \n restart code");
    display.display();
    delay(5000);
    Serial.println("No BME688 Connected, restart code");
    while (1) delay(1);  // Kills code, prevents processor from overworking this loop
  }

  bme.setHumidityOversampling(BME680_OS_16X);  // Uses library example standard, 16x for accuracy
  bme.setGasHeater(320, 150);                  // 320*C for 150 ms microscopic
  // Chose to not use temp in BME due to microscopic heat affecting accuracy

  if (!sht4.begin()) {  // Checks for if SHT45 is working
    display.clear();
    display.drawString(0, 0, "Couldn't find SHT4x");
    display.display();
    delay(5000);
    Serial.println("Couldn't find SHT4x");
    while (1) delay(1);  // Kills code, prevents processor from overworking this loop
  }

  sht4.setPrecision(SHT4X_HIGH_PRECISION);  // Used library example for high precison
  sht4.setHeater(SHT4X_NO_HEATER);          

  display.clear();
  display.drawString(0, 0, "Device Connected!");
  display.display();
  delay(5000);
  Serial.println("Device Connected!");
}


void bmefunc() {
  float gasSum = 0;
  float humidSum = 0;
  int kept = 0;
  for (int i = 0; i < 10; i++) {
    if (!bme.performReading()) {
      c = 1;
      display.clear();
      display.drawString(0, 0, "Failed to perform \n reading");
      display.display();
      delay(5000);

      Serial.println("Failed to perform reading");
      return;
    }
    if (i > 4) {
      gasSum += bme.gas_resistance / 1000.0;  // Converts to KOhms for more compressable readings
      humidSum += bme.humidity;
      kept++;
    }
    delay(2000);
  }
  SensorData.humid1 = humidSum / kept;
  SensorData.gas = gasSum / kept;  // Finds the average

  if ((SensorData.gas) < 1 || (SensorData.gas > 2000)) {  // Sets var to 1, checked later in the loop for failsafe
    x = 1;
    return;
  }
  if ((SensorData.humid1) < 0.1 || (SensorData.humid1 > 100.0)) {
    y = 1;
    return;
  }
}


void sht45func() {
  sensors_event_t humidity, temp;  // Creates two new variables
  sht4.setHeater(SHT4X_HIGH_HEATER_100MS);
  sht4.getEvent(&humidity, &temp);
  sht4.setHeater(SHT4X_NO_HEATER);
  delay(10000);

  if (!sht4.getEvent(&humidity, &temp)) {
    display.clear();
    display.drawString(0, 0, "SHT45 Cannot Read");
    display.display();
    delay(5000);
    Serial.println("SHT45 Cannot Read");
    d = 1;
    return;
  }
  SensorData.temp1 = temp.temperature;
  SensorData.humid2 = humidity.relative_humidity;

  if (SensorData.temp1 < -40.0 || (SensorData.temp1) > 125.0) {
    z = 1;
    return;
  }
  if (SensorData.humid2 < 0.0 || SensorData.humid2 > 100.0) {
    b = 1;
    return;
  }
}

void SMP() {  // Soil Moisture Probe
  SensorData.soilm = analogRead(SM_A);
  if (SensorData.soilm < 800 || SensorData.soilm > 3400) {
    a = 1;
    return;
  }
}

void loop() {
  heltec_loop();                              // Checks for button press
  if (millis() - lastRun < waitTime) return;  // Not enough time has passed
  lastRun = millis();                         // Enough time has passed, runs the loop
  heltec_led(50);
  display.displayOn();
  Serial.println("Running Sensors \n ETA 2 min:");
  display.clear();
  display.drawString(0, 0, "Running Sensors... \n ETA 1-2 min:");
  display.display();
  delay(5000);
  a = 0;
  b = 0;
  c = 0;
  d = 0;
  x = 0;
  y = 0;
  z = 0;  // resets all values for flags to catch
  delay(1000);
  bmefunc();
  delay(1000);
  sht45func();
  delay(1000);
  SMP();
  delay(1000);

  Serial.println("Data Collected! \n Proceeding with Radio");
  display.clear();
  display.drawString(0, 0, "Data Collected! \n Proceeding with Radio");
  display.display();
  delay(5000);


  if (a == 1.0 || b == 1.0 || c == 1.0 || d == 1.0 || x == 1.0 || y == 1.0 || z == 1.0) {  // If any value is equal to 1, run failsafe
    iter++;
    if (iter == 3) {  // If sensor loop ran through 3 times with fail, end code
      Serial.println("Sensor Damaged, Not Receiving Info After 3 Attempts. Please Repair and Reset");
      display.clear();
      display.drawString(0, 0, "Sensor Damaged, \n Not Receiving Info \n After 3 Attempts. \n Please Repair \n and Reset");
      display.display();
      delay(5000);
      heltec_led(0);
      while (1) delay(1);  // Stops all code
    }
    heltec_led(0);
    Serial.println("Sensors Failed, Retrying");
    display.clear();
    display.drawString(0, 0, "Sensors Failed, Retrying");
    display.display();
    delay(5000);
    waitTime = 0;
    return;
  }

  String lora_msg = String(SensorData.nodeid, HEX) + "|" + String(SensorData.sequence) + "|\n" + String(SensorData.temp1) + "|" + String(SensorData.humid1) + "|\n" + String(SensorData.humid2) + "|" + String(SensorData.soilm) + "|\n" + String(SensorData.gas);  // Defining the packet that will be sent over LoRa added in \n

  // Packet format: nodeid|sequence|temp1|humid1|humid2|soilm|gas

  if (radio.transmit(lora_msg)) {  // Would be !radio.transmit, however, sucess for this command returns a 0, which is also false, so we don't use !
    // Sends the message through an if statement
    display.clear();
    display.drawString(0, 0, "Radio Transmit \n Failed, Retrying");
    display.display();
    delay(10000);  // Lets everything have time to get ready to run the loop again and for the user to see the radio failed
    radioiter++;

    if (radioiter == 3) {  // If radio loop ran through 3 times with fail, end code
      Serial.println("Radio Damaged, Not Receiving Info After 3 Attempts. Please Repair and Reset");
      display.clear();
      display.drawString(0, 0, "Radio Damaged, \n Not Receiving Info \n After 3 Attempts. \n Please Repair \n and Reset");
      display.display();
      delay(5000);
      heltec_led(0);
      while (1) delay(1);  // Stops all code
    }

    waitTime = 0;
    return;

  } else {
    Serial.println("Radio Transmit Sucessful!");
    display.clear();
    display.drawString(0, 0, "Radio Transmit \n Sucessful!");
    display.display();
    delay(5000);
    iter = 0;
    radioiter = 0;
    SensorData.sequence++;  // Adds one to the Sequence variable inside the struct
    both.println("Going to Sleep until \n Next Data Round...");
    delay(5000);
    both.println("");
    display.displayOff();
  }
  heltec_led(0);         // Turns LED off
  display.clear();       // added in
  waitTime = 1500000UL;  // 25 minute delay for next round
}

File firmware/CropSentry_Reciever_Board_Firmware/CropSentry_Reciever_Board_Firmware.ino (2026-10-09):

#include <heltec_unofficial.h>
#include <WiFiManager.h>
#include <HTTPClient.h>


#define PAUSE 300
#define FREQUENCY 905.2
#define BANDWIDTH 500.0
#define SPREADING_FACTOR 9
#define TRANSMIT_POWER 0

// Lines 10-11 copied from WiFiClentConnect WiFi.h library

volatile bool packetReady = false;
String data;
int a = 0;  // Flag for an issue with the sending system taking too many attempts to repair
int b = 0;  // Flag for an issue with seeing if info was ever sent
int c = 0;  // Flag for if network needs reconnection without full reset
unsigned long startTime = 0;
unsigned long waitLength = 0;
bool waiting = false;


void IRAM_ATTR onPacket() {
  packetReady = true;
}

void setup() {
  // put your setup code here, to run once:
  heltec_setup();
  Serial.begin(115200);
  WiFiManager wm;
  heltec_ve(true);  // Uses on-board VEXT pin for the displays 3V3 power source
  delay(100);
  pinMode(21, OUTPUT);
  digitalWrite(21, LOW);
  delay(50);
  digitalWrite(21, HIGH);
  delay(50);  // Sets pin 21 (display controller) LOW and HIGH for power configuration

  display.init();
  display.flipScreenVertically();

  both.print("Device Starting...");
  delay(5000);

  both.println("Hold PRG to \n Reset WiFi");
  delay(2500);
  if (digitalRead(BUTTON) == LOW) {
    wm.resetSettings();
  }
  delay(10000);

  display.clear();

  both.println("Connect to the Board \n WiFi System. \n You will be prompted \n with further instructions");

  bool res;
  // res = wm.autoConnect(); // auto generated AP name from chipid
  // res = wm.autoConnect("CropSentry WiFi Portal"); // anonymous ap
  res = wm.autoConnect("CropSentry-Module-WiFi", "password");  // password protected ap

  if (!res) {
    both.println("Failed to connect \n Please try again \n Restarting...");
    delay(2000);
    ESP.restart();
  } else {
    //if you get here you have connected to the WiFi
    both.println("WiFi Connected \n Proceeding...");
  }

  // Lines 28 and 41-53 pasted from the WifiManager.h library

  both.println("Radio Initiating...");
  RADIOLIB_OR_HALT(radio.begin());
  // Set the callback function for received packets
  radio.setDio1Action(onPacket);
  // Set radio parameters
  both.printf("Frequency: %.2f MHz\n", FREQUENCY);
  RADIOLIB_OR_HALT(radio.setFrequency(FREQUENCY));
  both.printf("Bandwidth: %.1f kHz\n", BANDWIDTH);
  RADIOLIB_OR_HALT(radio.setBandwidth(BANDWIDTH));
  both.printf("Spreading Factor: %i\n", SPREADING_FACTOR);
  RADIOLIB_OR_HALT(radio.setSpreadingFactor(SPREADING_FACTOR));
  both.printf("TX power: %i dBm\n", TRANSMIT_POWER);
  RADIOLIB_OR_HALT(radio.setOutputPower(TRANSMIT_POWER));
  // Start receiving

  RADIOLIB_OR_HALT(radio.startReceive(RADIOLIB_SX126X_RX_TIMEOUT_INF));


  both.println("WiFi Receiver Board \n Activated \n Looking for Radio... \n Will Sleep \n until Signal Received");
  delay(8000);
  display.clear();
}

void wifiSetup() {
  WiFiManager wm;
  bool res;
  // res = wm.autoConnect(); // auto generated AP name from chipid
  // res = wm.autoConnect("CropSentry WiFi Portal"); // anonymous ap
  res = wm.autoConnect("CropSentry-Module-WiFi", "password");  // password protected ap

  if (!res) {
    both.println("Failed to connect \n Please try again \n Restarting...");
    delay(2000);
    ESP.restart();
  } else {
    //if you get here you have connected to the WiFi
    both.println("WiFi Connected \n Proceeding...");
  }
}
void sendServer() {
  if (a >= 5) {
    both.println("Sending System Damaged \n Please Repair");
    while (1) delay(1);
  }
  HTTPClient http;
  Serial.print("[HTTP] begin...\n");
  // configure traged server and url
  http.begin("https://www.example.com");  // Link to server
  Serial.print("[HTTP] POST...\n");
  // start connection and send HTTP header
  http.addHeader("Content-Type", "text/plain");
  int httpCode = http.POST(data);  // Sends STR var from sensor module to server
                                   // httpCode will be negative on error


  if (httpCode == 404 || httpCode == 400) {
    both.println("Server Code Failure \n Error Code 404/400 \n Ending Processes...");
    http.end();
    while (1) delay(1);


  } else if (httpCode == 408 || httpCode == 429) {
    both.println("Processing Error \n Retrying...");
    delay(5000);
    display.clear();
    http.end();
    a++;
    b = 1;
    return;
  }

  else if (httpCode == 500 || httpCode == 503) {
    both.println("Server Under Maintenance \n Retrying in 5 min...");
    http.end();
    a++;
    b = 0;
    c = 0;
    startTime = millis();
    waitLength = 300000UL;
    waiting = true;
    return;

  } else if (httpCode == 403 || httpCode == 401) {
    both.println("Server Refusing User \n Shutting Down...");
    http.end();
    while (1) delay(1);

  } else if (httpCode == 413) {
    both.println("Sending Data \n too Large \n Code needs Repair");
    http.end();
    while (1) delay(1);

  } 
  
    else if (httpCode <= 299 && httpCode >= 200) {
    both.println("Data Verified! \n Continuing \n Waiting on Next Packet...");
    delay(5000);
    display.clear();
    http.end();
    a = 0;
    b = 0;
    c = 0;
    return;
  }
  
  else if (httpCode > 0) {
    // HTTP header has been send and Server response header has been handled
    both.println("Checking Server \n for Confirmation...");
    http.end();
    // file found at server
  } else if (httpCode < 0) {
    both.println("Network Failure \n Error Code Sub-0 \n Trying Again...");
    http.end();
    c = 1;
    a++;
  }


  else {
    both.println("Issue with Server \n Communication \n Retrying...");
    b = 1;
    a++;
    http.end();
  }
}


void loop() {
  heltec_loop();
  if (millis() - startTime >= waitLength && waiting == true) {
    waiting = false;
    sendServer();
  }

  if (c == 1) {
    delay(1000);
    wifiSetup();
    delay(1000);
    sendServer();
  }
  if (b == 1) {
    delay(1000);
    sendServer();
  }

  if (packetReady) {
    packetReady = false;
    int state = radio.readData(data);
    both.println("Packet Received \n Processing...");
    delay(1000);
    radio.startReceive(RADIOLIB_SX126X_RX_TIMEOUT_INF);
    if (state == RADIOLIB_ERR_NONE) {
      delay(500);
      both.println(data);
      delay(4500);
      display.clear();
      if (waiting == false && b == 0 && c == 0) {
        both.println("Sending to Server...");
        delay(1000);
        sendServer();
      } else {
        both.println("Retry Pending \n Data Queued");
      }
    }
  }
}

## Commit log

2026-09-15 Added PDF of CropSentry Schematic
    We plan to hand-wire, but this leaves PCB fabrication as a viable option.
2026-09-15 CropSentry Hardware Materials 9-15-2026
    All materials for the CropSentry Hardware side of the projects
    Date: 9-15-2026
    Version: 0.0.1
    [CropSentry.kicad_sch]
2026-09-18 Added CSV for a BOM
    [CropSentry_Hardware_BOM_9-14-26.csv]
2026-09-28 Replace CropSentry materials
    [.kicad_sch, BME688_Module.f3d, BME688_Module.step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]
2026-09-30 Add Data Flow section to README
    Added a section on data flow with architecture diagrams.
2026-09-30 Add schematic section to README
2026-10-06 Replace CropSentry materials with updated version
    [BME688_Module.f3d, BME688_Module.step, Capacitive_Soil_Moisture_Probe_Module.f3d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]
2026-10-09 Replace repo contents with updated CropSentry files
    [.kicad_sch, BME688_Module.f3d, BME688_Module.step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]
2026-10-09 Refine sensor descriptions in README.md
    Updated descriptions for SGP41, BME688, and SHT45 sensors for clarity and conciseness.
2026-10-16 Revise Bill of Materials and update pricing
    Updated the budget and parts status in the Bill of Materials section. Adjusted prices and marked items as purchased.
2026-10-19 Add device information confidence data to README
    Added device information confidence section with accuracy rates for various sensors.
